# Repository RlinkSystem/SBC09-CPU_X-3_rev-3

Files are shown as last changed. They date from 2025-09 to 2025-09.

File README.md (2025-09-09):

# SBC09-CPU_X-3_rev-3

Simple SBC design around MC6809 Revision 3

This is the second atemp/test to make a full SBC system based on my old
modem X-3 construction, and keep it simpel.

This was done during Summer holiday 2025.
To test my simple & basic setup, and continue to experiment.

My goal is to have an uncomplex build that is not compact, so:
* not with a few large ICs
* not with PAL/GAL
* and with "many" ICs

So my setup is:
* CPU: MC68B09/HD63C09
* MEM: 7x HM6264ALP-15
* ROM: 2764 eq EPROM / EEPROM
* PTM: MC6840
* ACIA: 2x MC6850
* ACIA: R6551
* PIA: 3x MC6821
* Glue logic:
  * 74HCT04
  * 4x 74HCT138
  * 74HCT4040 Baud Rate
* Test support for USB-TTL-UART
  * CH340E (CH340X)

My testing setup:
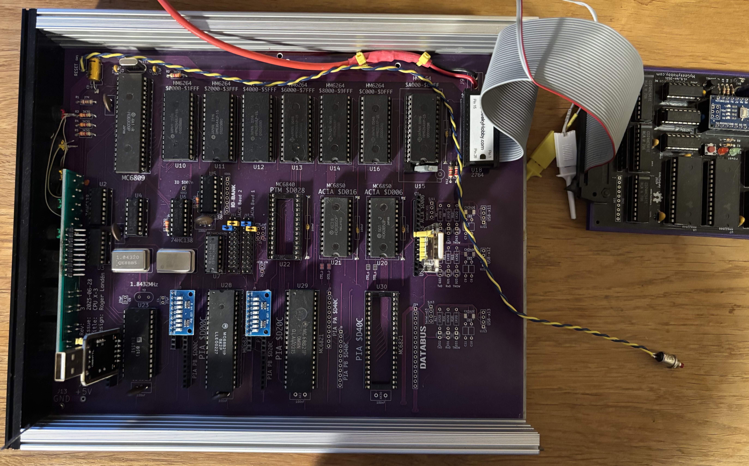
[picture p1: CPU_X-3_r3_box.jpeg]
PCB in case


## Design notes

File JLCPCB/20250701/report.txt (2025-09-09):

Plotted to '/Users/rogerlanden/Z180/6809/CPU_X-3/CPU_X-3-v2/JLCPCB/PCB_CPU_X-3_v2/PCB_CPU_X_3/CPU_X-3-F_Cu.gtl'.
Plotted to '/Users/rogerlanden/Z180/6809/CPU_X-3/CPU_X-3-v2/JLCPCB/PCB_CPU_X-3_v2/PCB_CPU_X_3/CPU_X-3-B_Cu.gbl'.
Plotted to '/Users/rogerlanden/Z180/6809/CPU_X-3/CPU_X-3-v2/JLCPCB/PCB_CPU_X-3_v2/PCB_CPU_X_3/CPU_X-3-F_Paste.gtp'.
Plotted to '/Users/rogerlanden/Z180/6809/CPU_X-3/CPU_X-3-v2/JLCPCB/PCB_CPU_X-3_v2/PCB_CPU_X_3/CPU_X-3-B_Paste.gbp'.
Plotted to '/Users/rogerlanden/Z180/6809/CPU_X-3/CPU_X-3-v2/JLCPCB/PCB_CPU_X-3_v2/PCB_CPU_X_3/CPU_X-3-F_Silkscreen.gto'.
Plotted to '/Users/rogerlanden/Z180/6809/CPU_X-3/CPU_X-3-v2/JLCPCB/PCB_CPU_X-3_v2/PCB_CPU_X_3/CPU_X-3-B_Silkscreen.gbo'.
Plotted to '/Users/rogerlanden/Z180/6809/CPU_X-3/CPU_X-3-v2/JLCPCB/PCB_CPU_X-3_v2/PCB_CPU_X_3/CPU_X-3-F_Mask.gts'.
Plotted to '/Users/rogerlanden/Z180/6809/CPU_X-3/CPU_X-3-v2/JLCPCB/PCB_CPU_X-3_v2/PCB_CPU_X_3/CPU_X-3-B_Mask.gbs'.
Plotted to '/Users/rogerlanden/Z180/6809/CPU_X-3/CPU_X-3-v2/JLCPCB/PCB_CPU_X-3_v2/PCB_CPU_X_3/CPU_X-3-Edge_Cuts.gm1'.
Info: Done.
Info: Done.

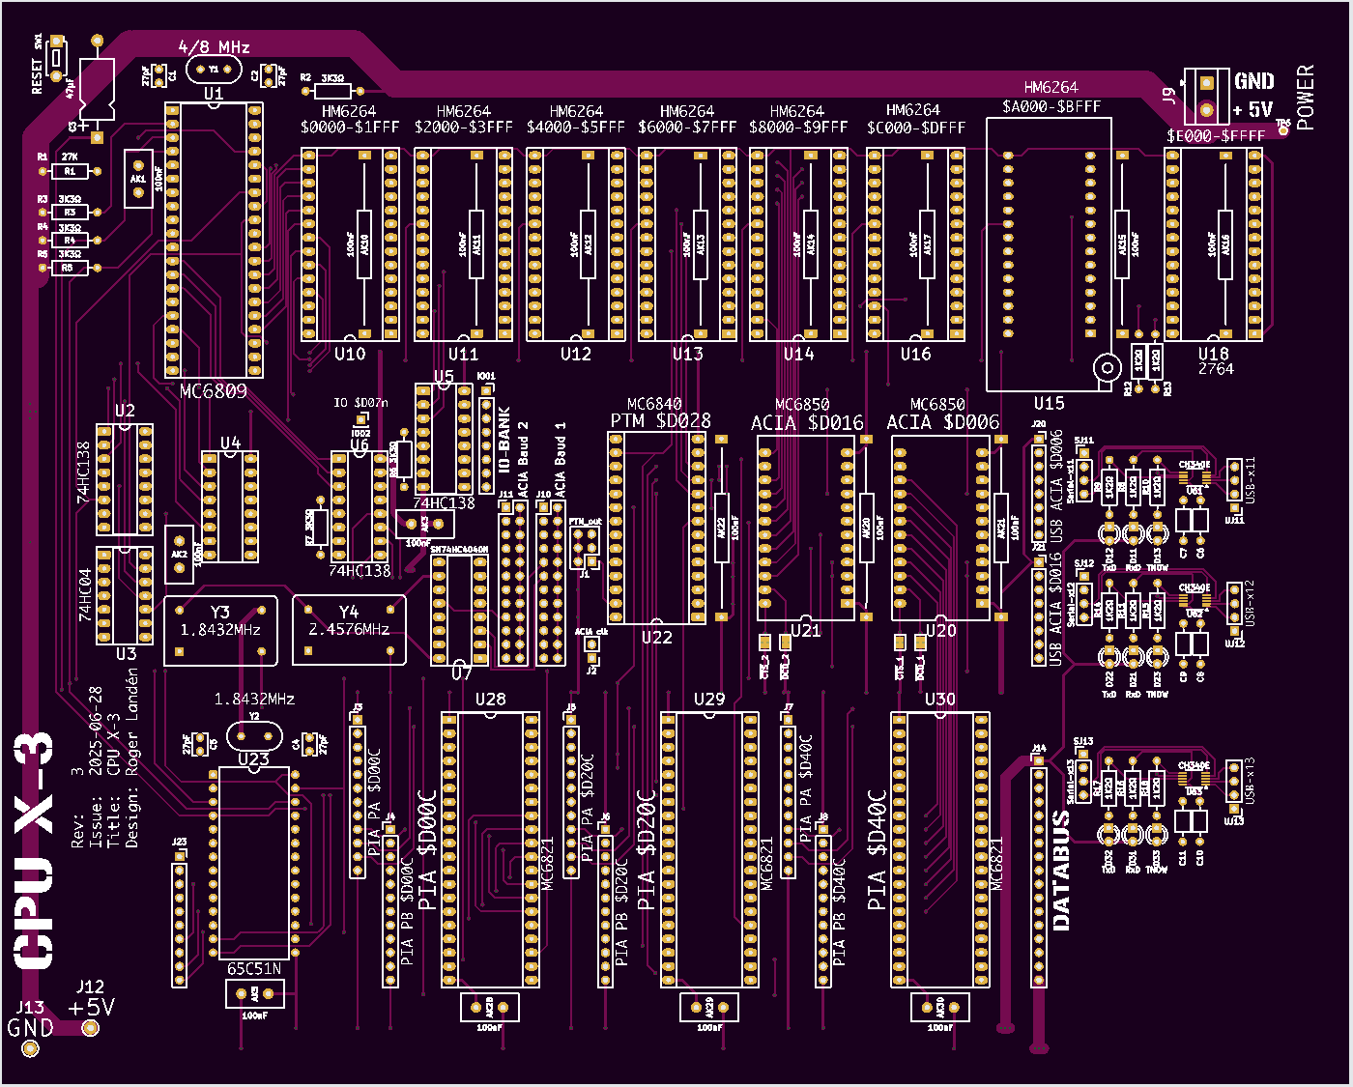
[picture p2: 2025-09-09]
JLCPCB/20250701/PCB_Lila_top.png

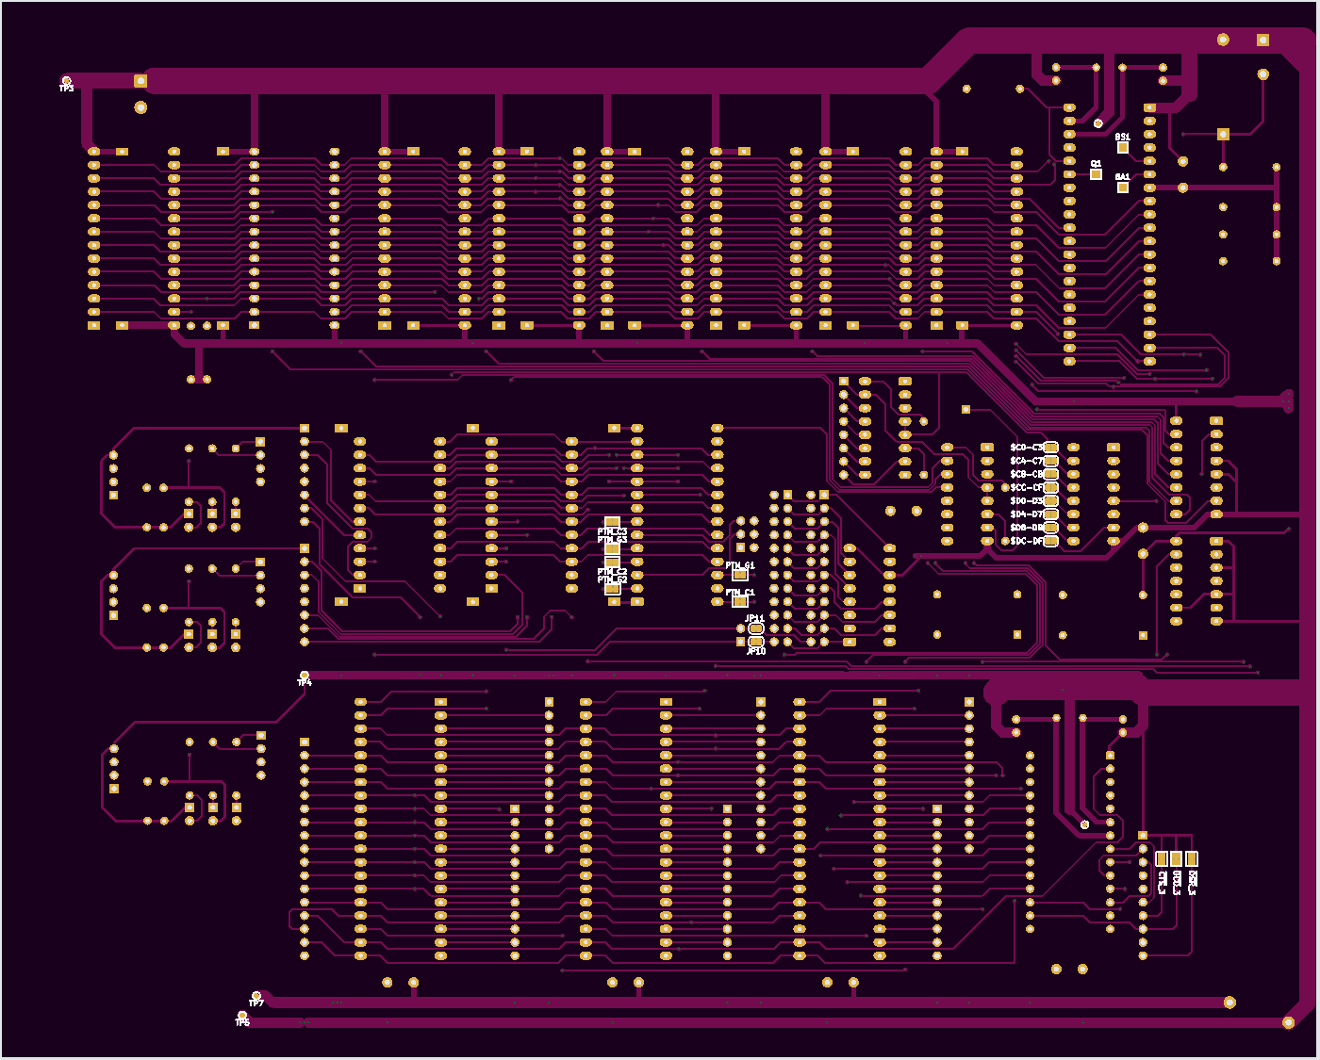
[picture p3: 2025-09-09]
JLCPCB/20250701/PCB_Lila_botom.png

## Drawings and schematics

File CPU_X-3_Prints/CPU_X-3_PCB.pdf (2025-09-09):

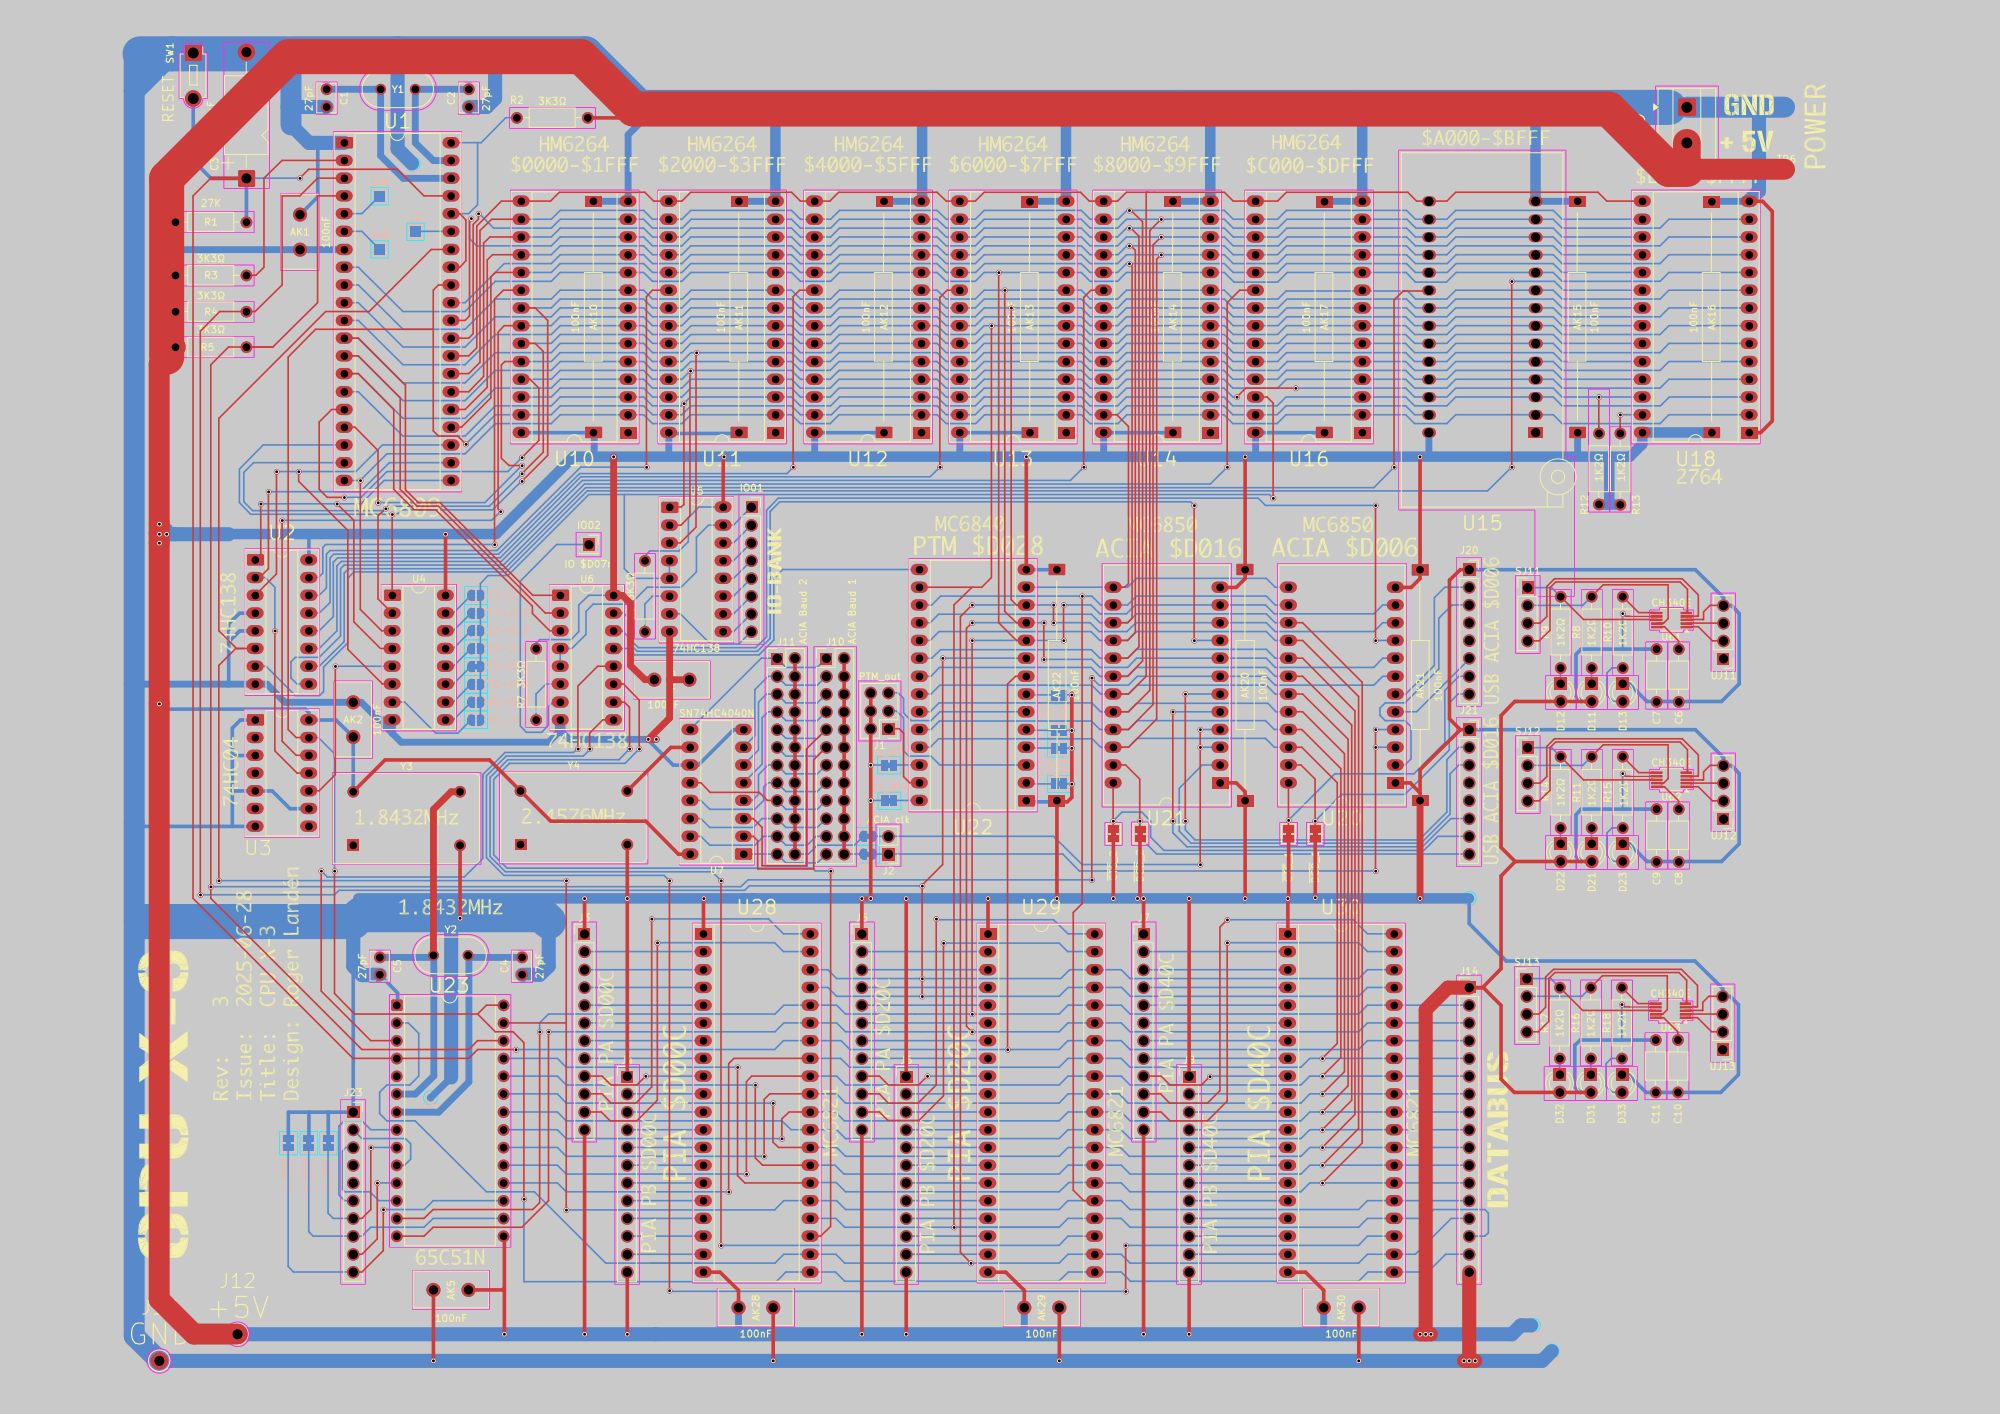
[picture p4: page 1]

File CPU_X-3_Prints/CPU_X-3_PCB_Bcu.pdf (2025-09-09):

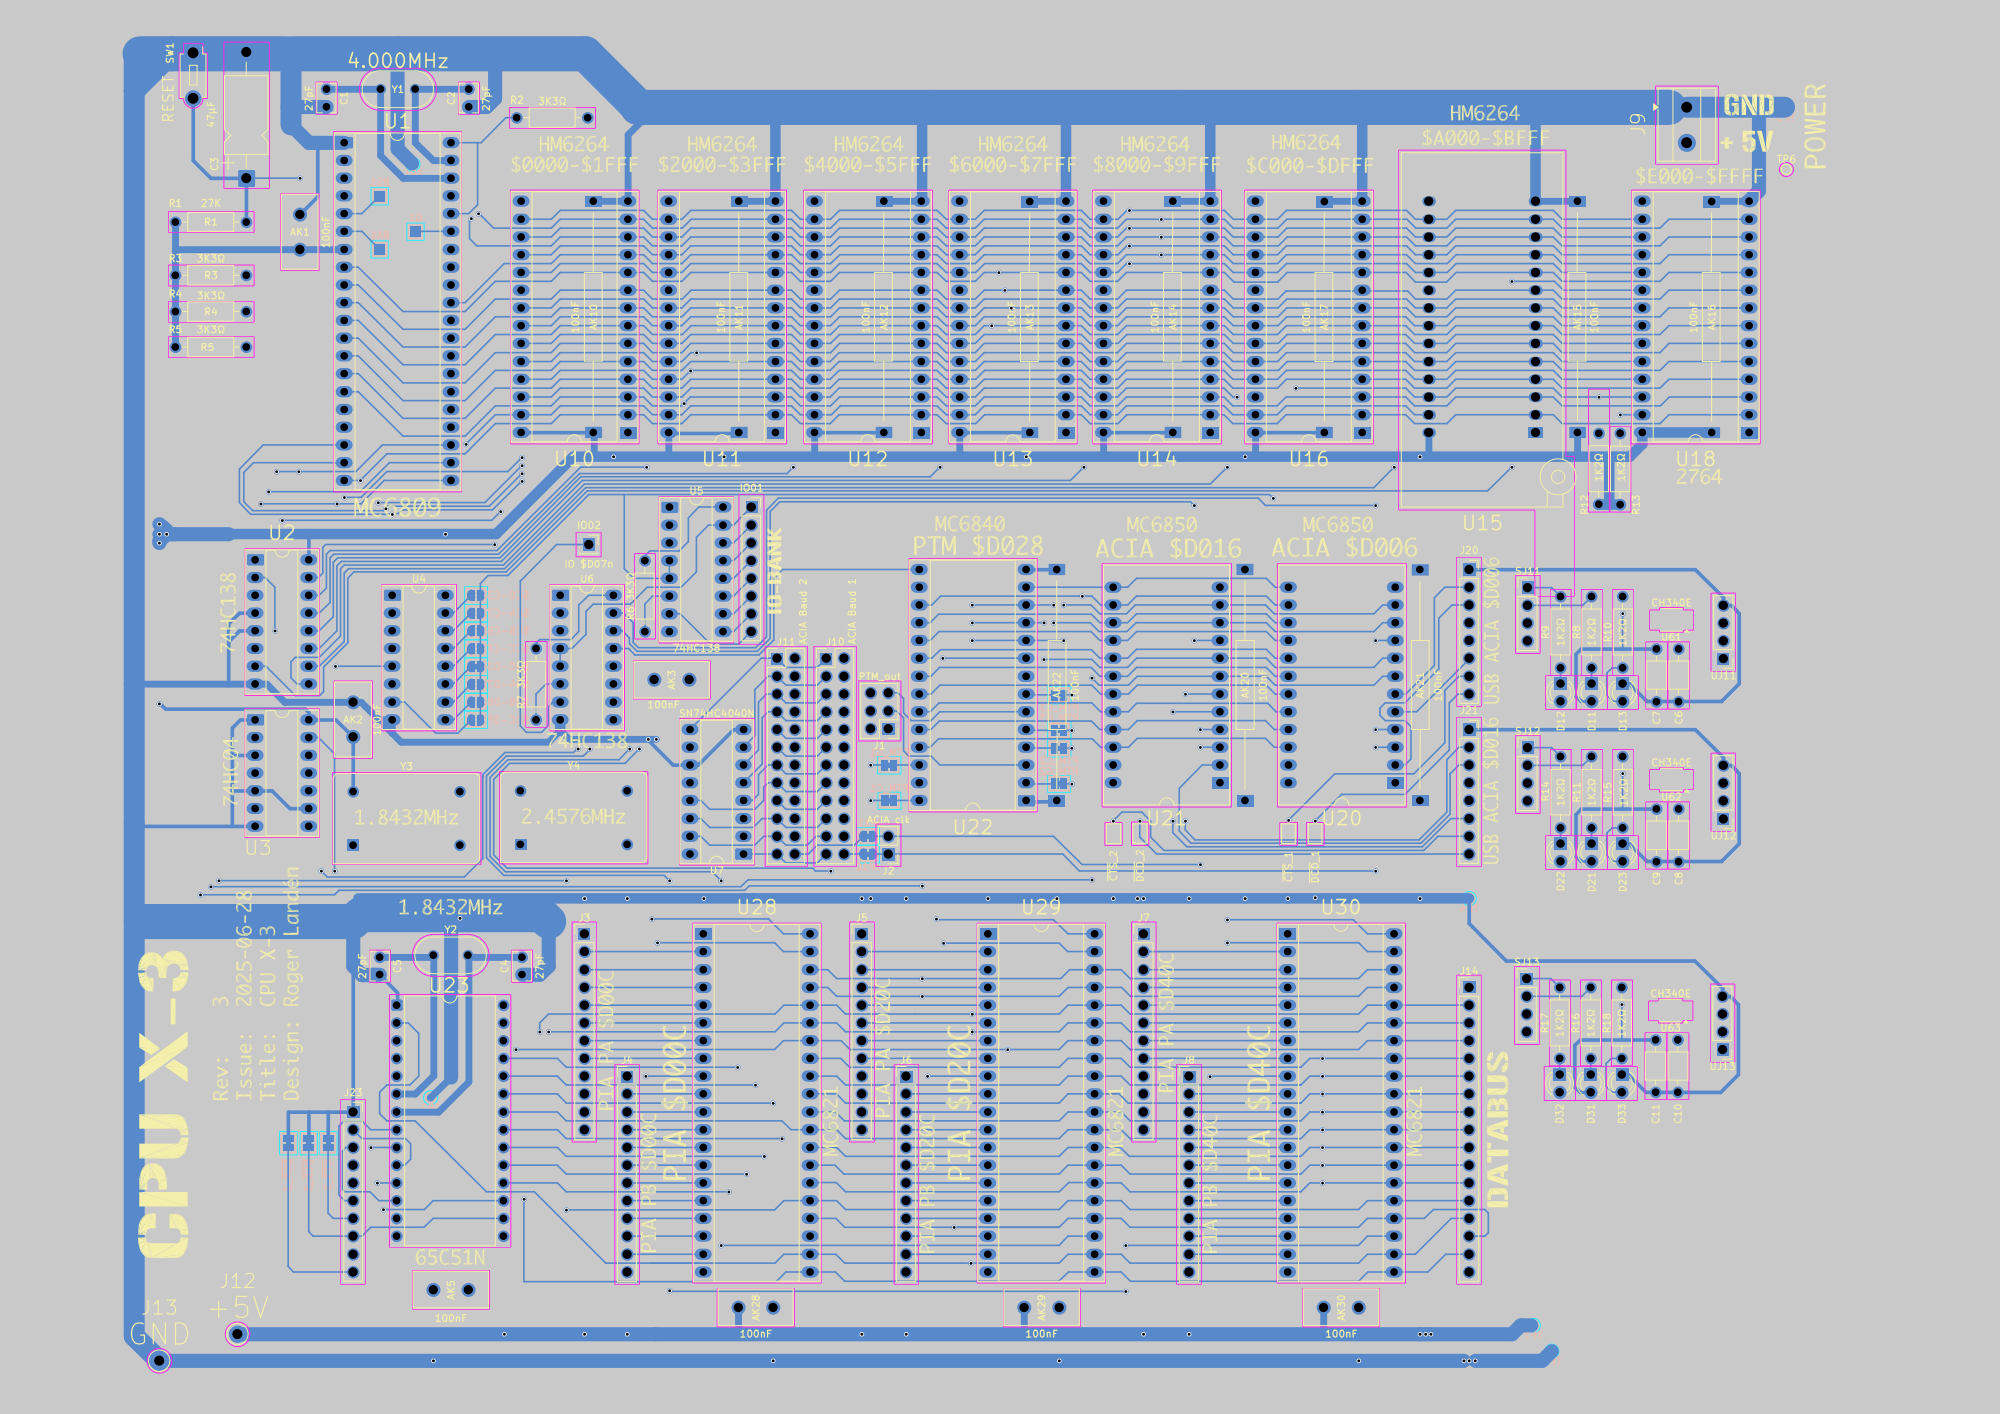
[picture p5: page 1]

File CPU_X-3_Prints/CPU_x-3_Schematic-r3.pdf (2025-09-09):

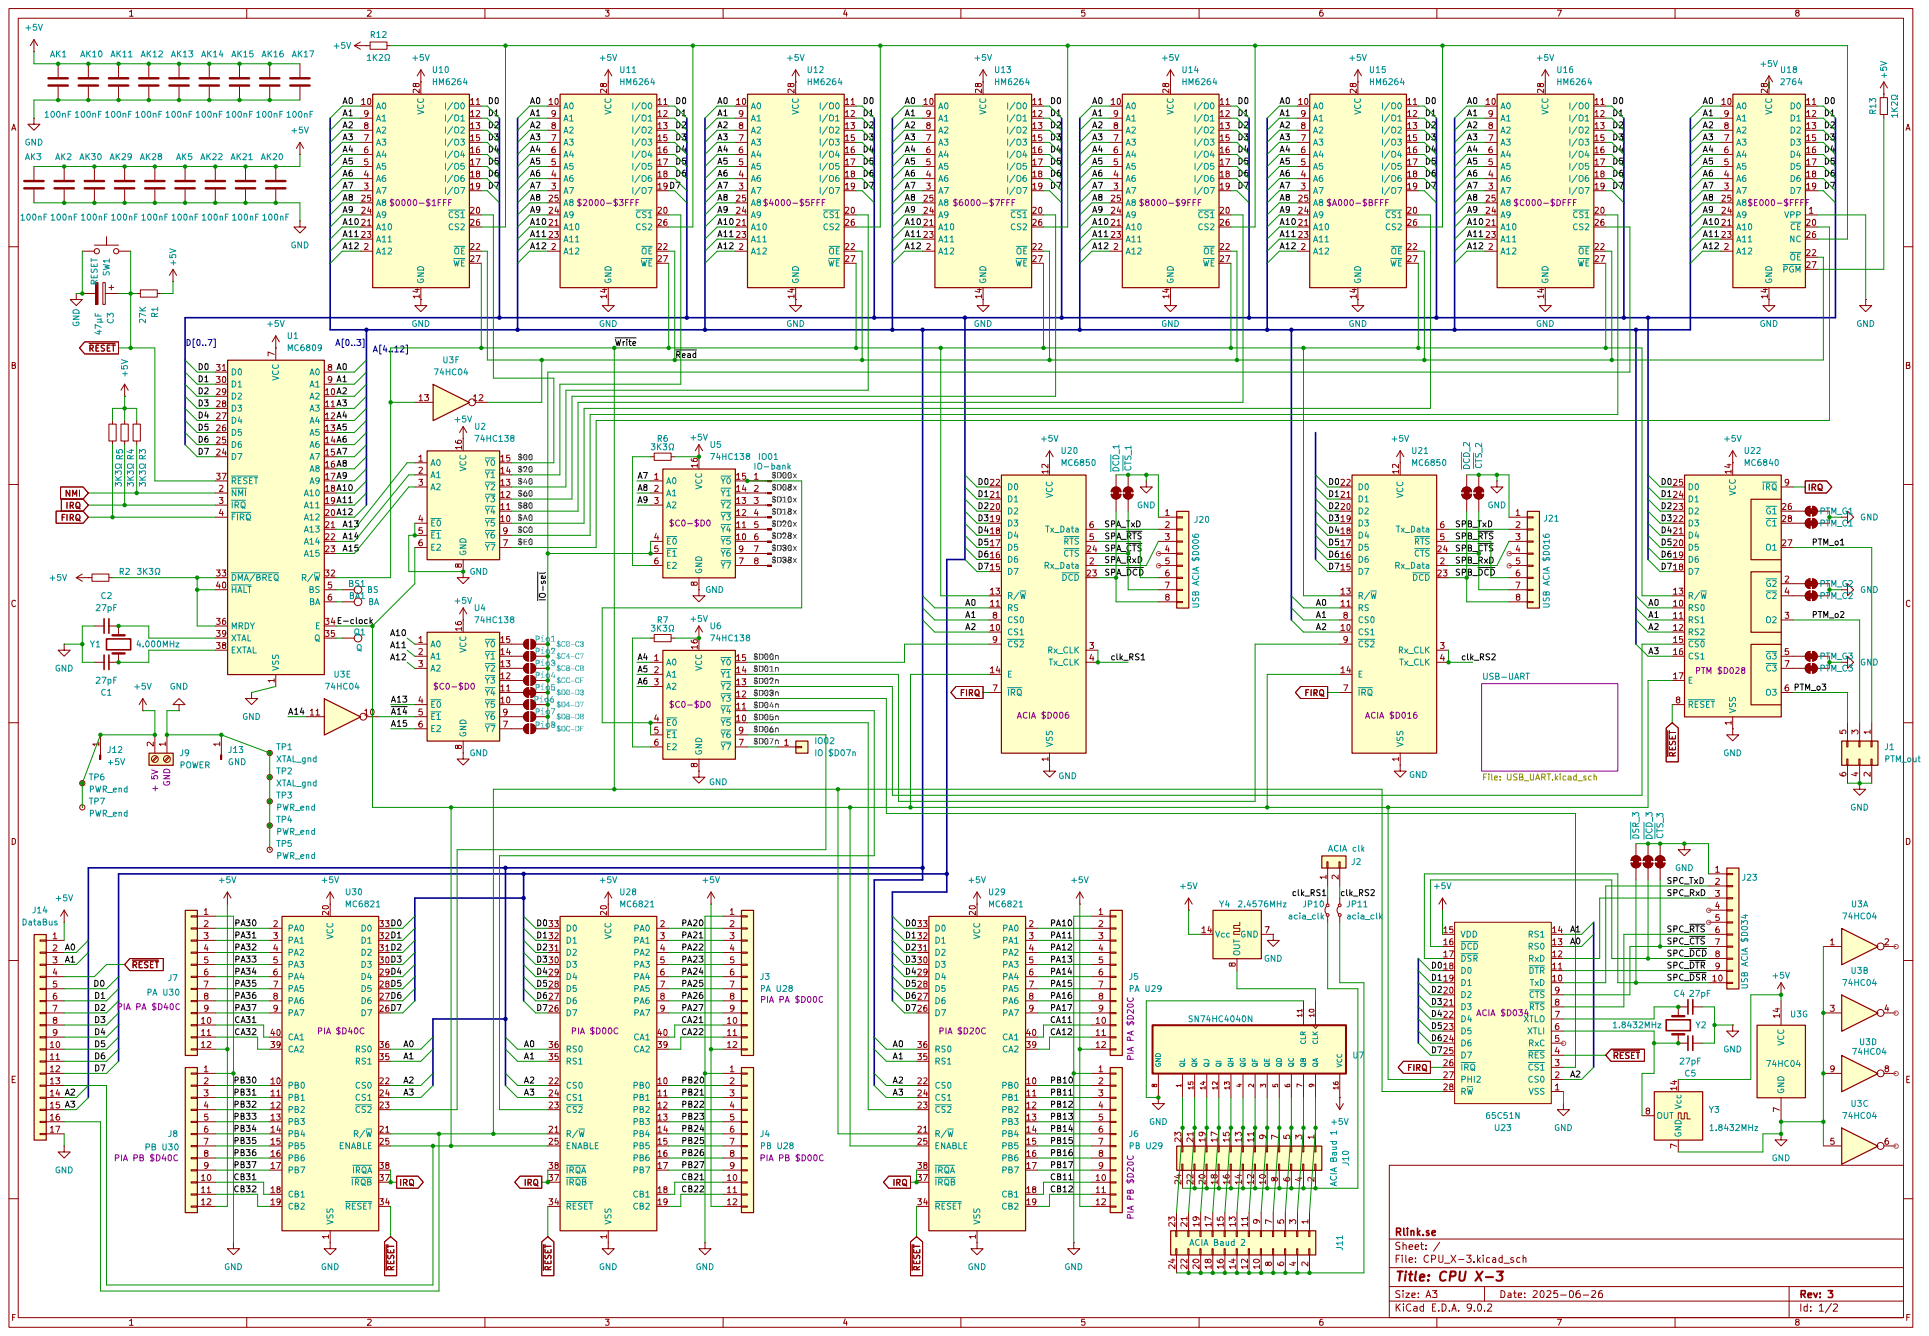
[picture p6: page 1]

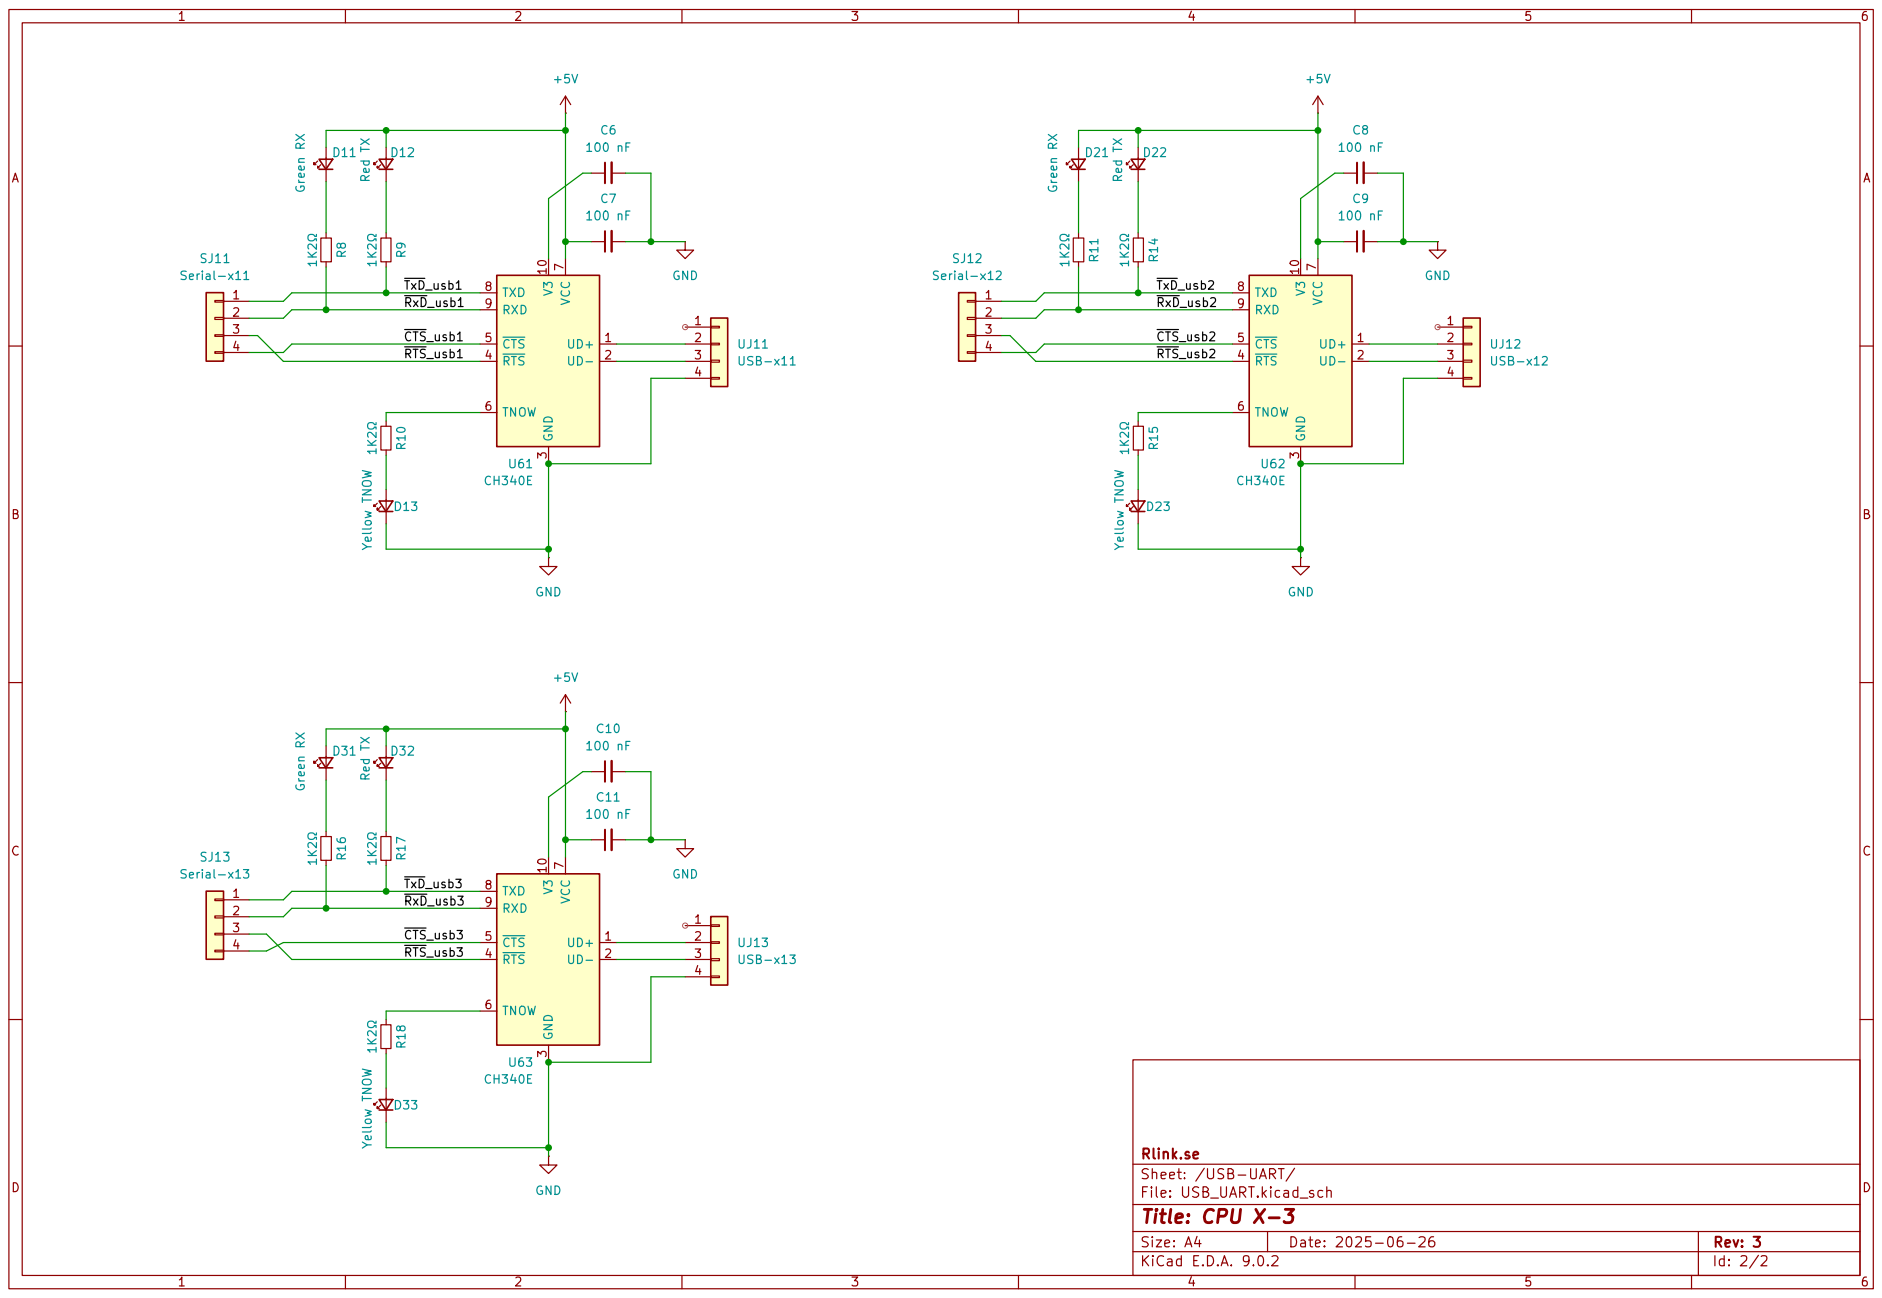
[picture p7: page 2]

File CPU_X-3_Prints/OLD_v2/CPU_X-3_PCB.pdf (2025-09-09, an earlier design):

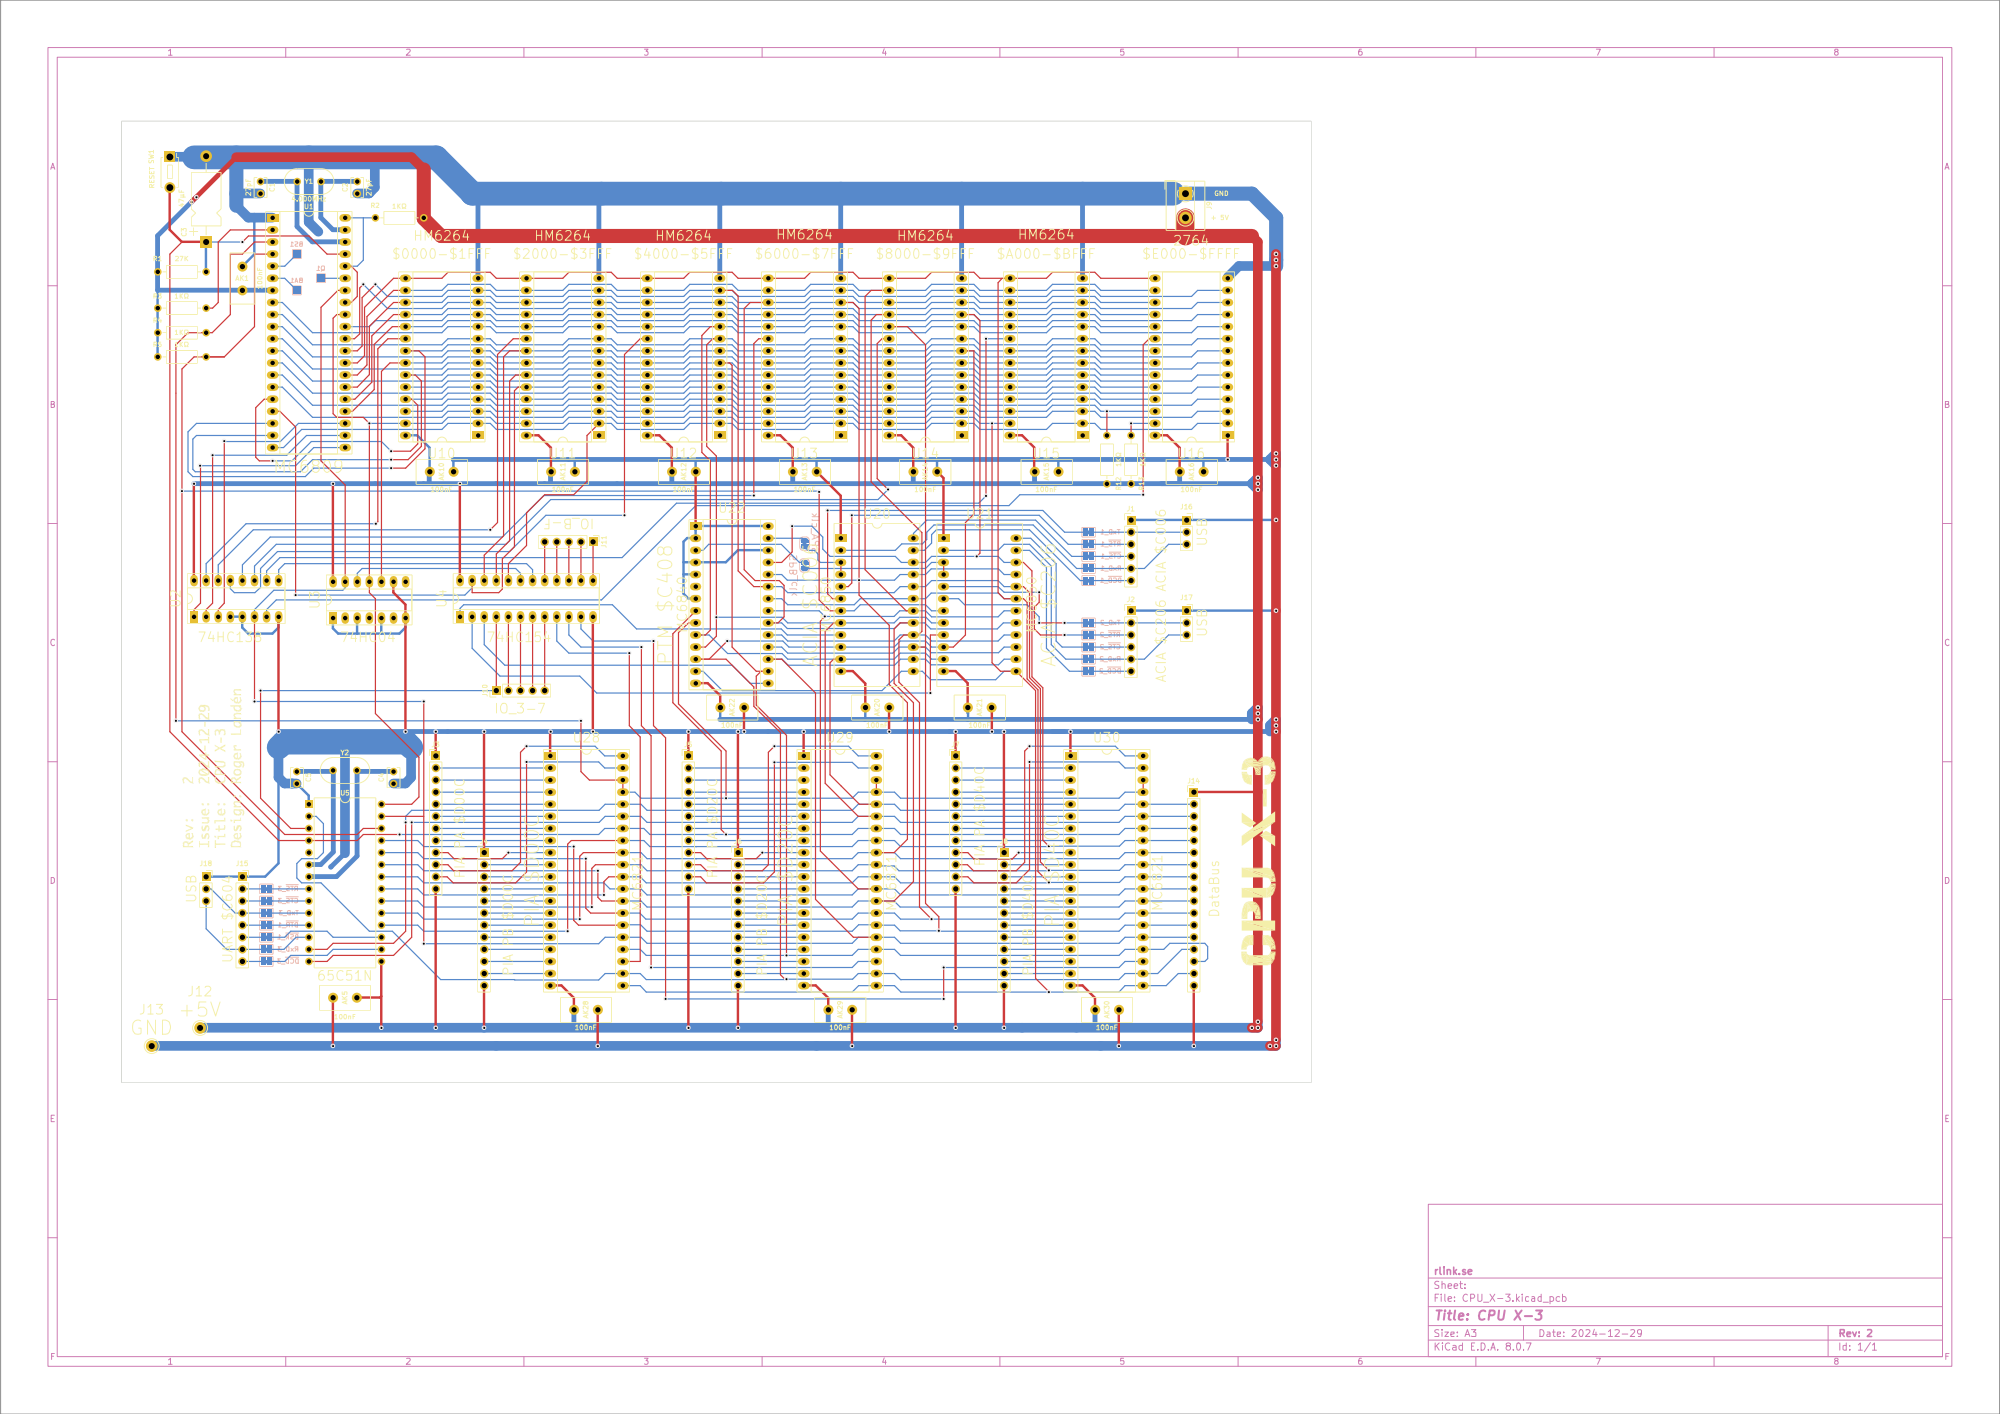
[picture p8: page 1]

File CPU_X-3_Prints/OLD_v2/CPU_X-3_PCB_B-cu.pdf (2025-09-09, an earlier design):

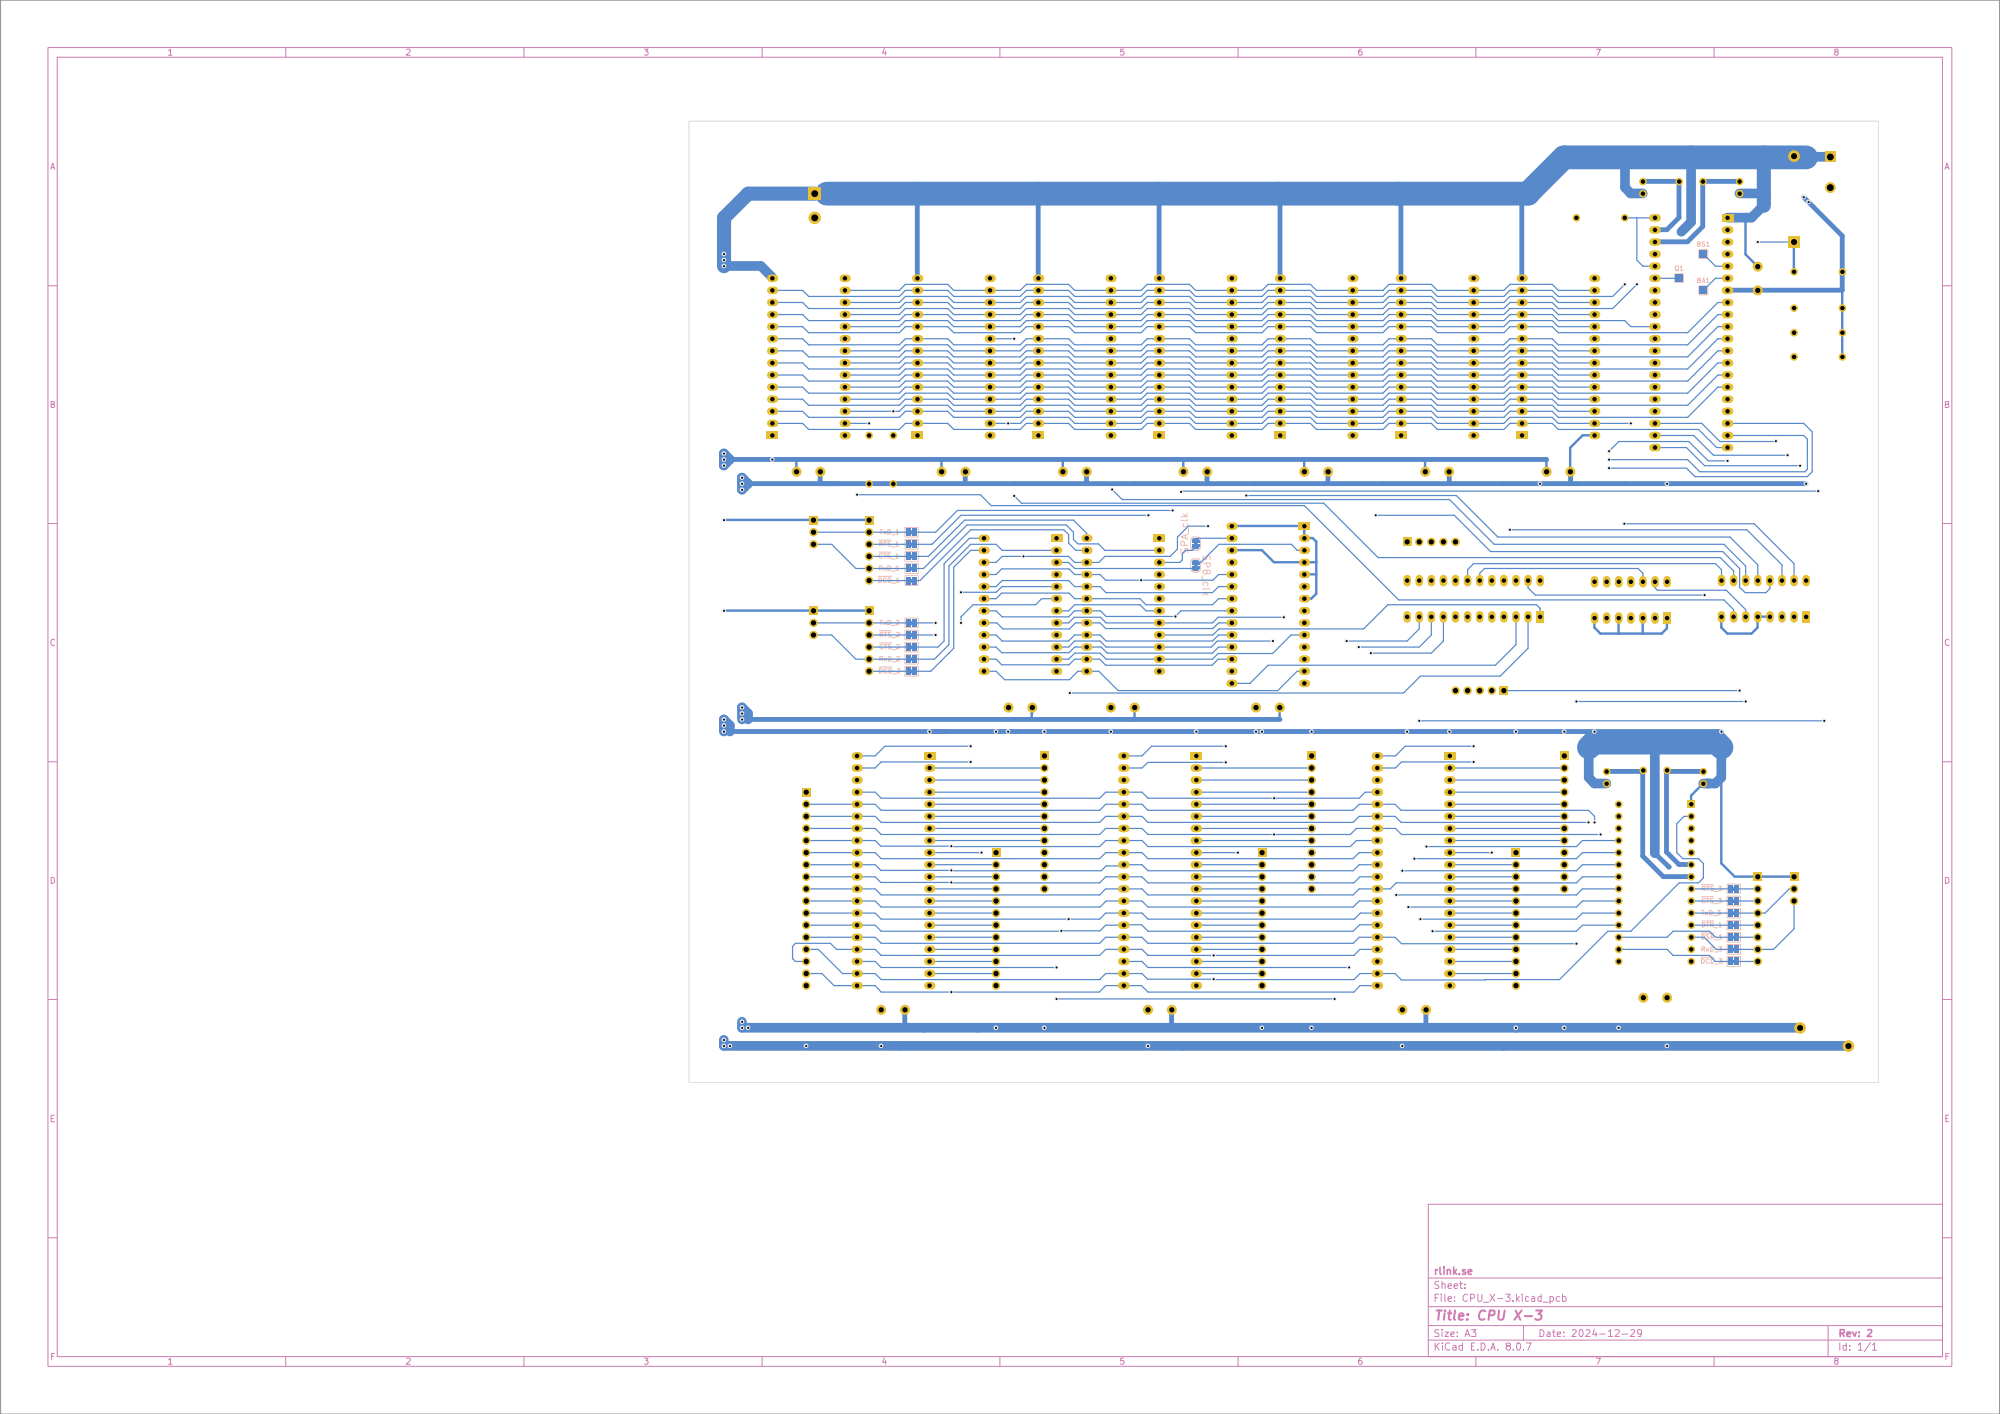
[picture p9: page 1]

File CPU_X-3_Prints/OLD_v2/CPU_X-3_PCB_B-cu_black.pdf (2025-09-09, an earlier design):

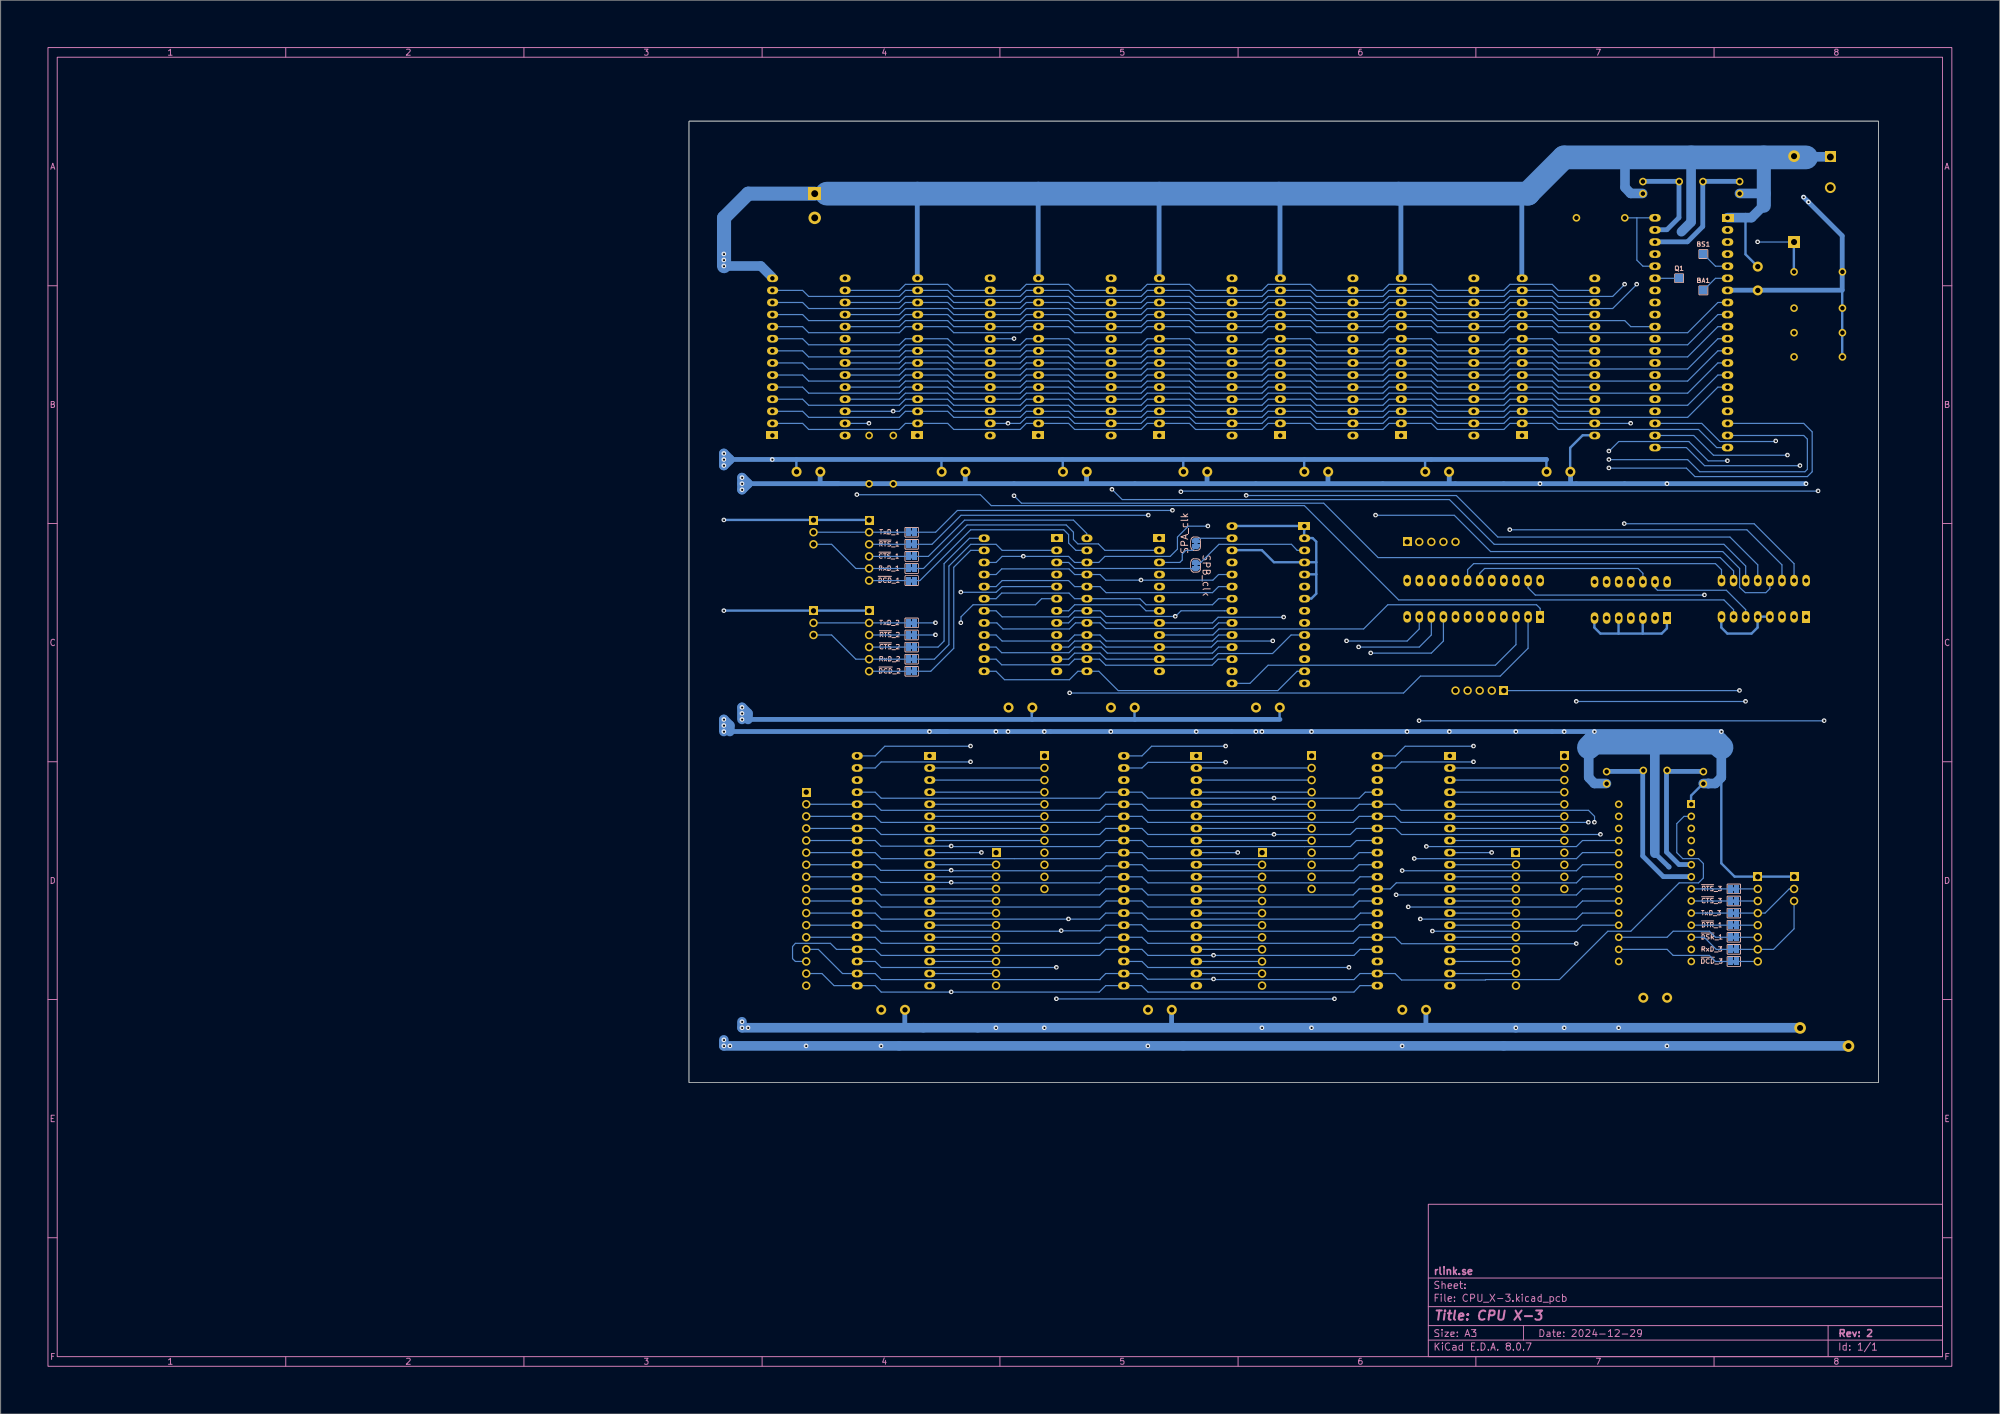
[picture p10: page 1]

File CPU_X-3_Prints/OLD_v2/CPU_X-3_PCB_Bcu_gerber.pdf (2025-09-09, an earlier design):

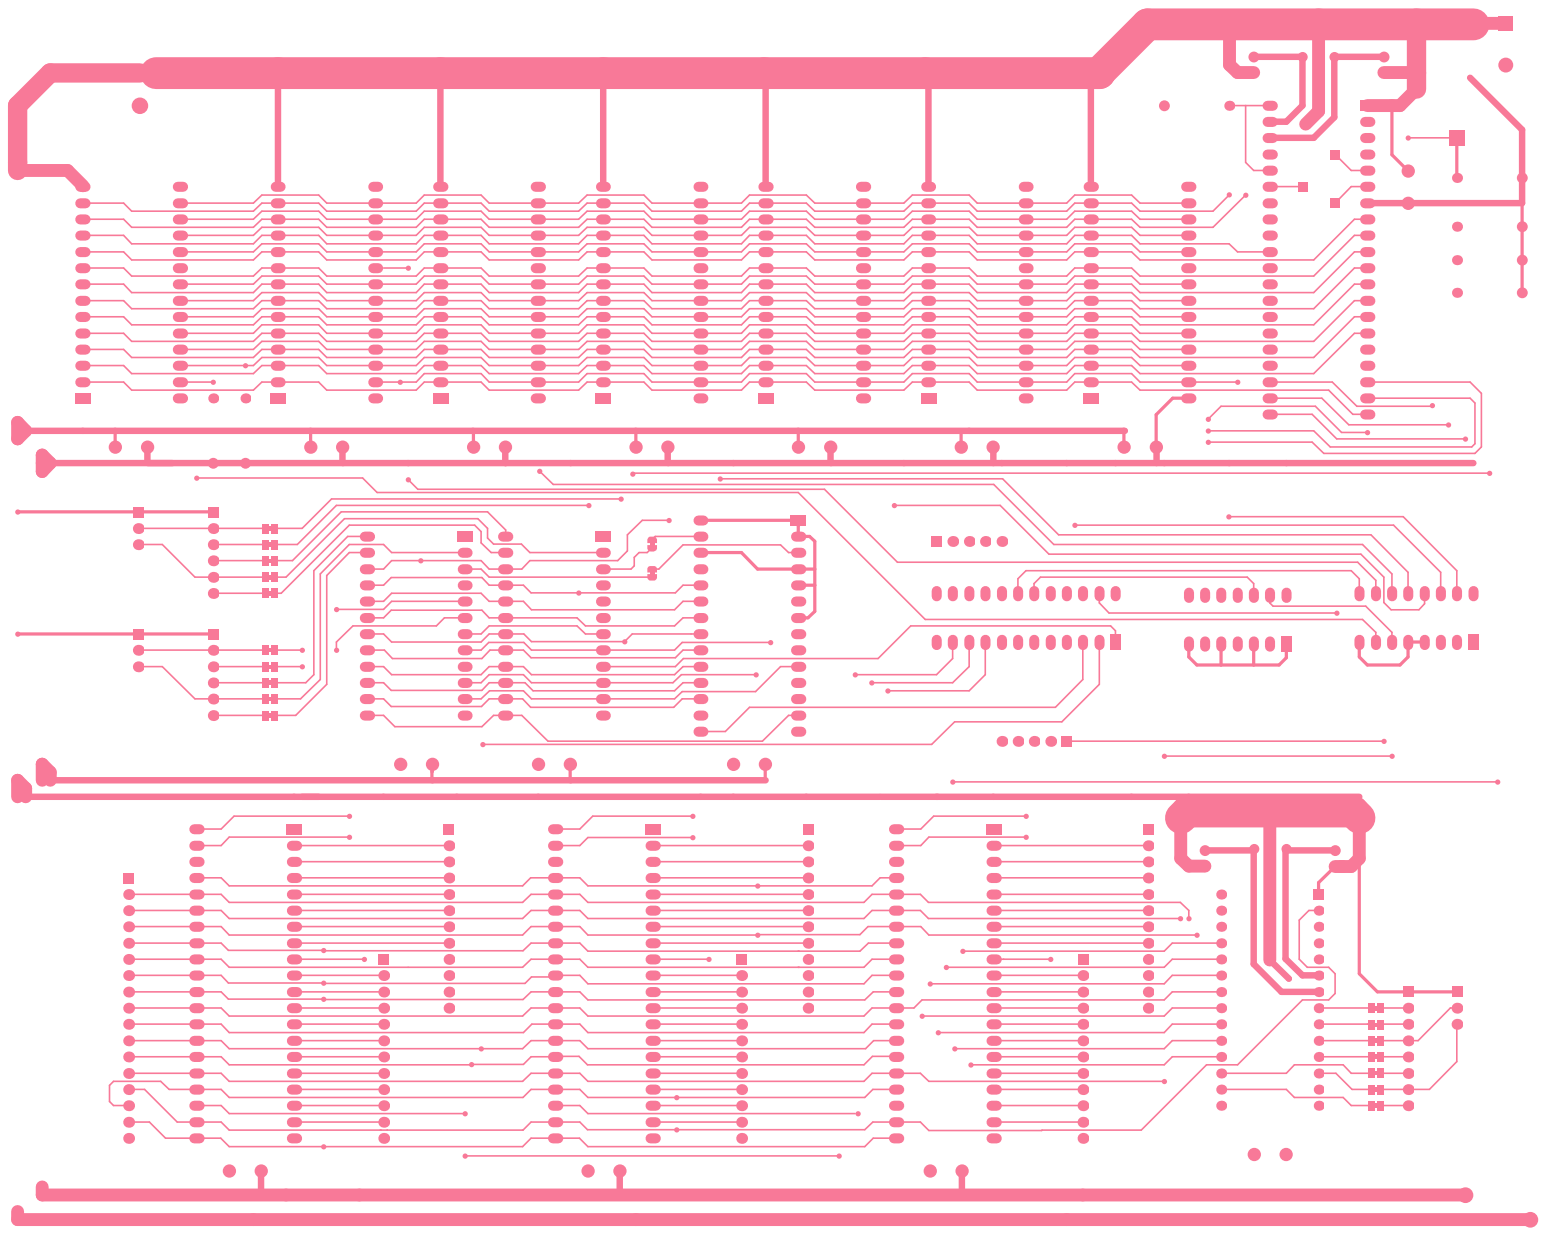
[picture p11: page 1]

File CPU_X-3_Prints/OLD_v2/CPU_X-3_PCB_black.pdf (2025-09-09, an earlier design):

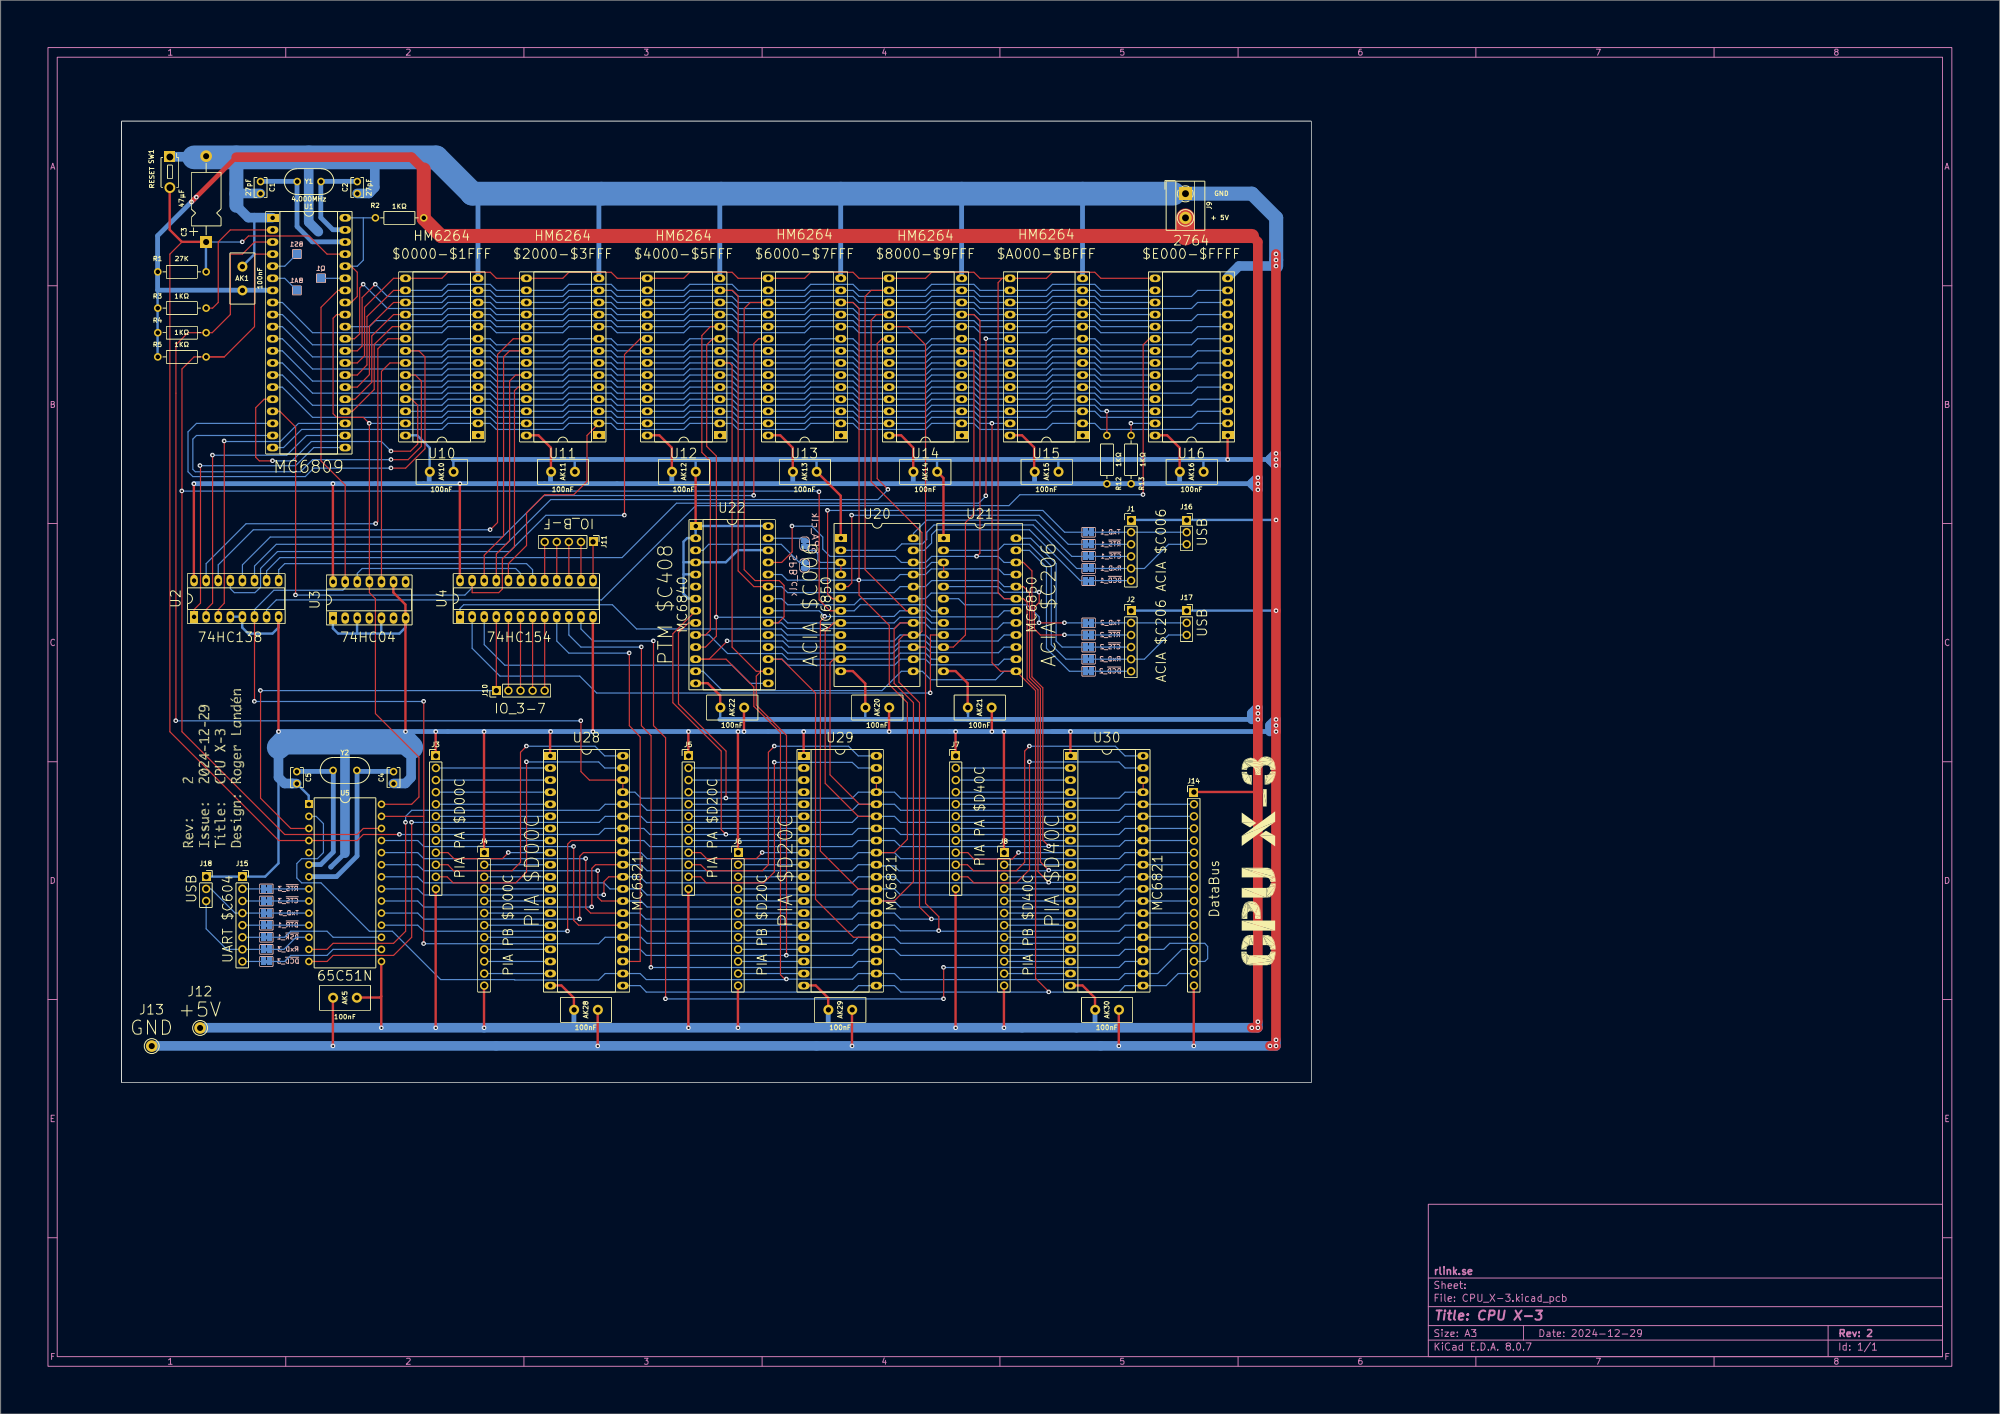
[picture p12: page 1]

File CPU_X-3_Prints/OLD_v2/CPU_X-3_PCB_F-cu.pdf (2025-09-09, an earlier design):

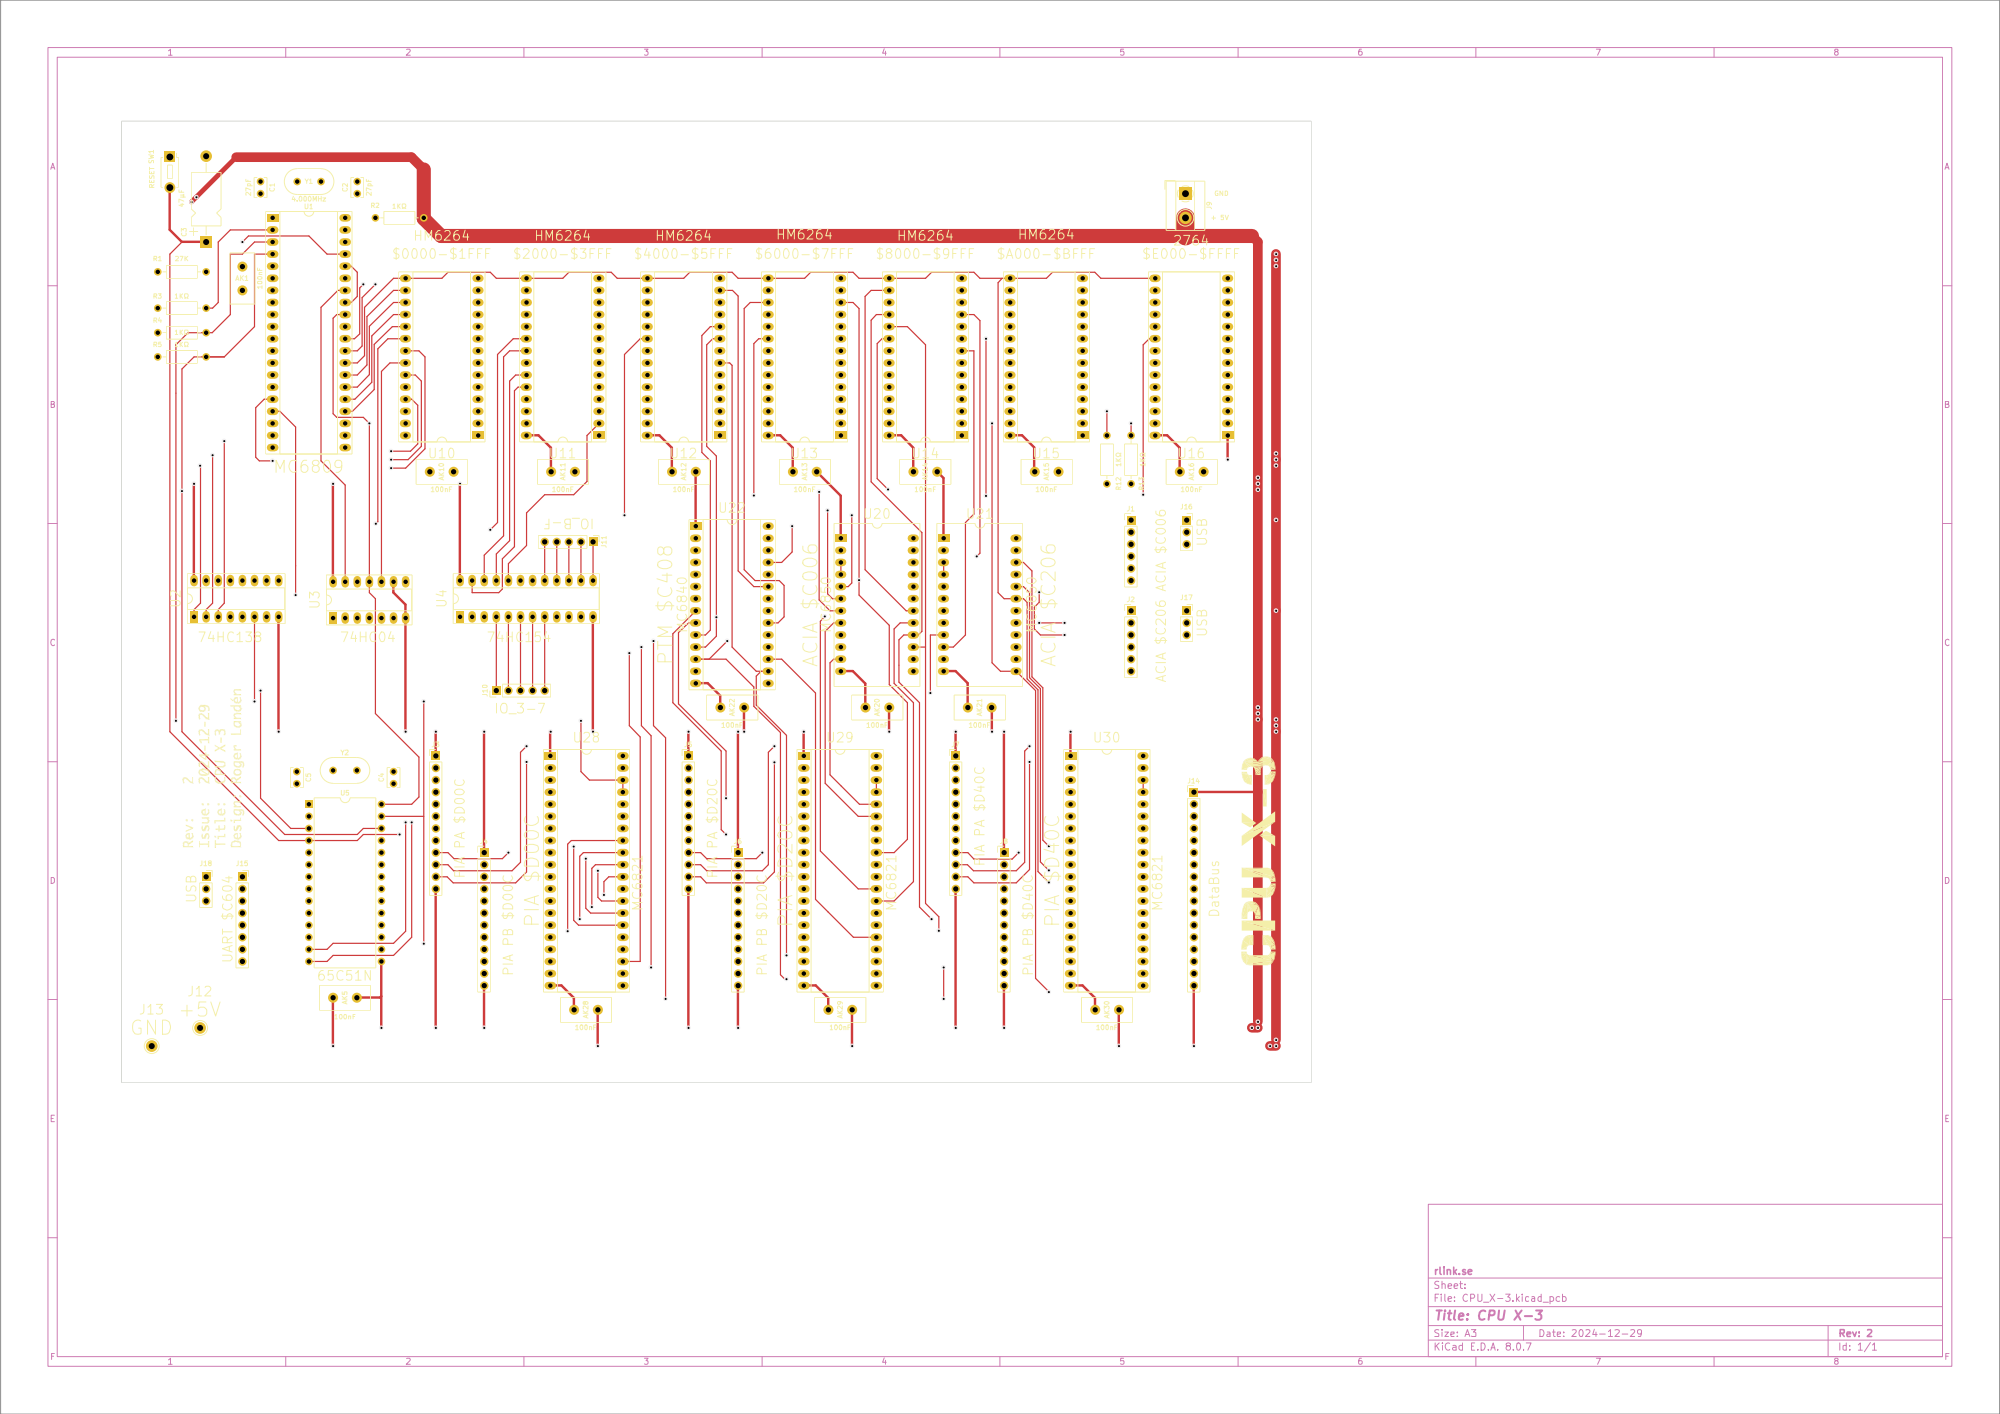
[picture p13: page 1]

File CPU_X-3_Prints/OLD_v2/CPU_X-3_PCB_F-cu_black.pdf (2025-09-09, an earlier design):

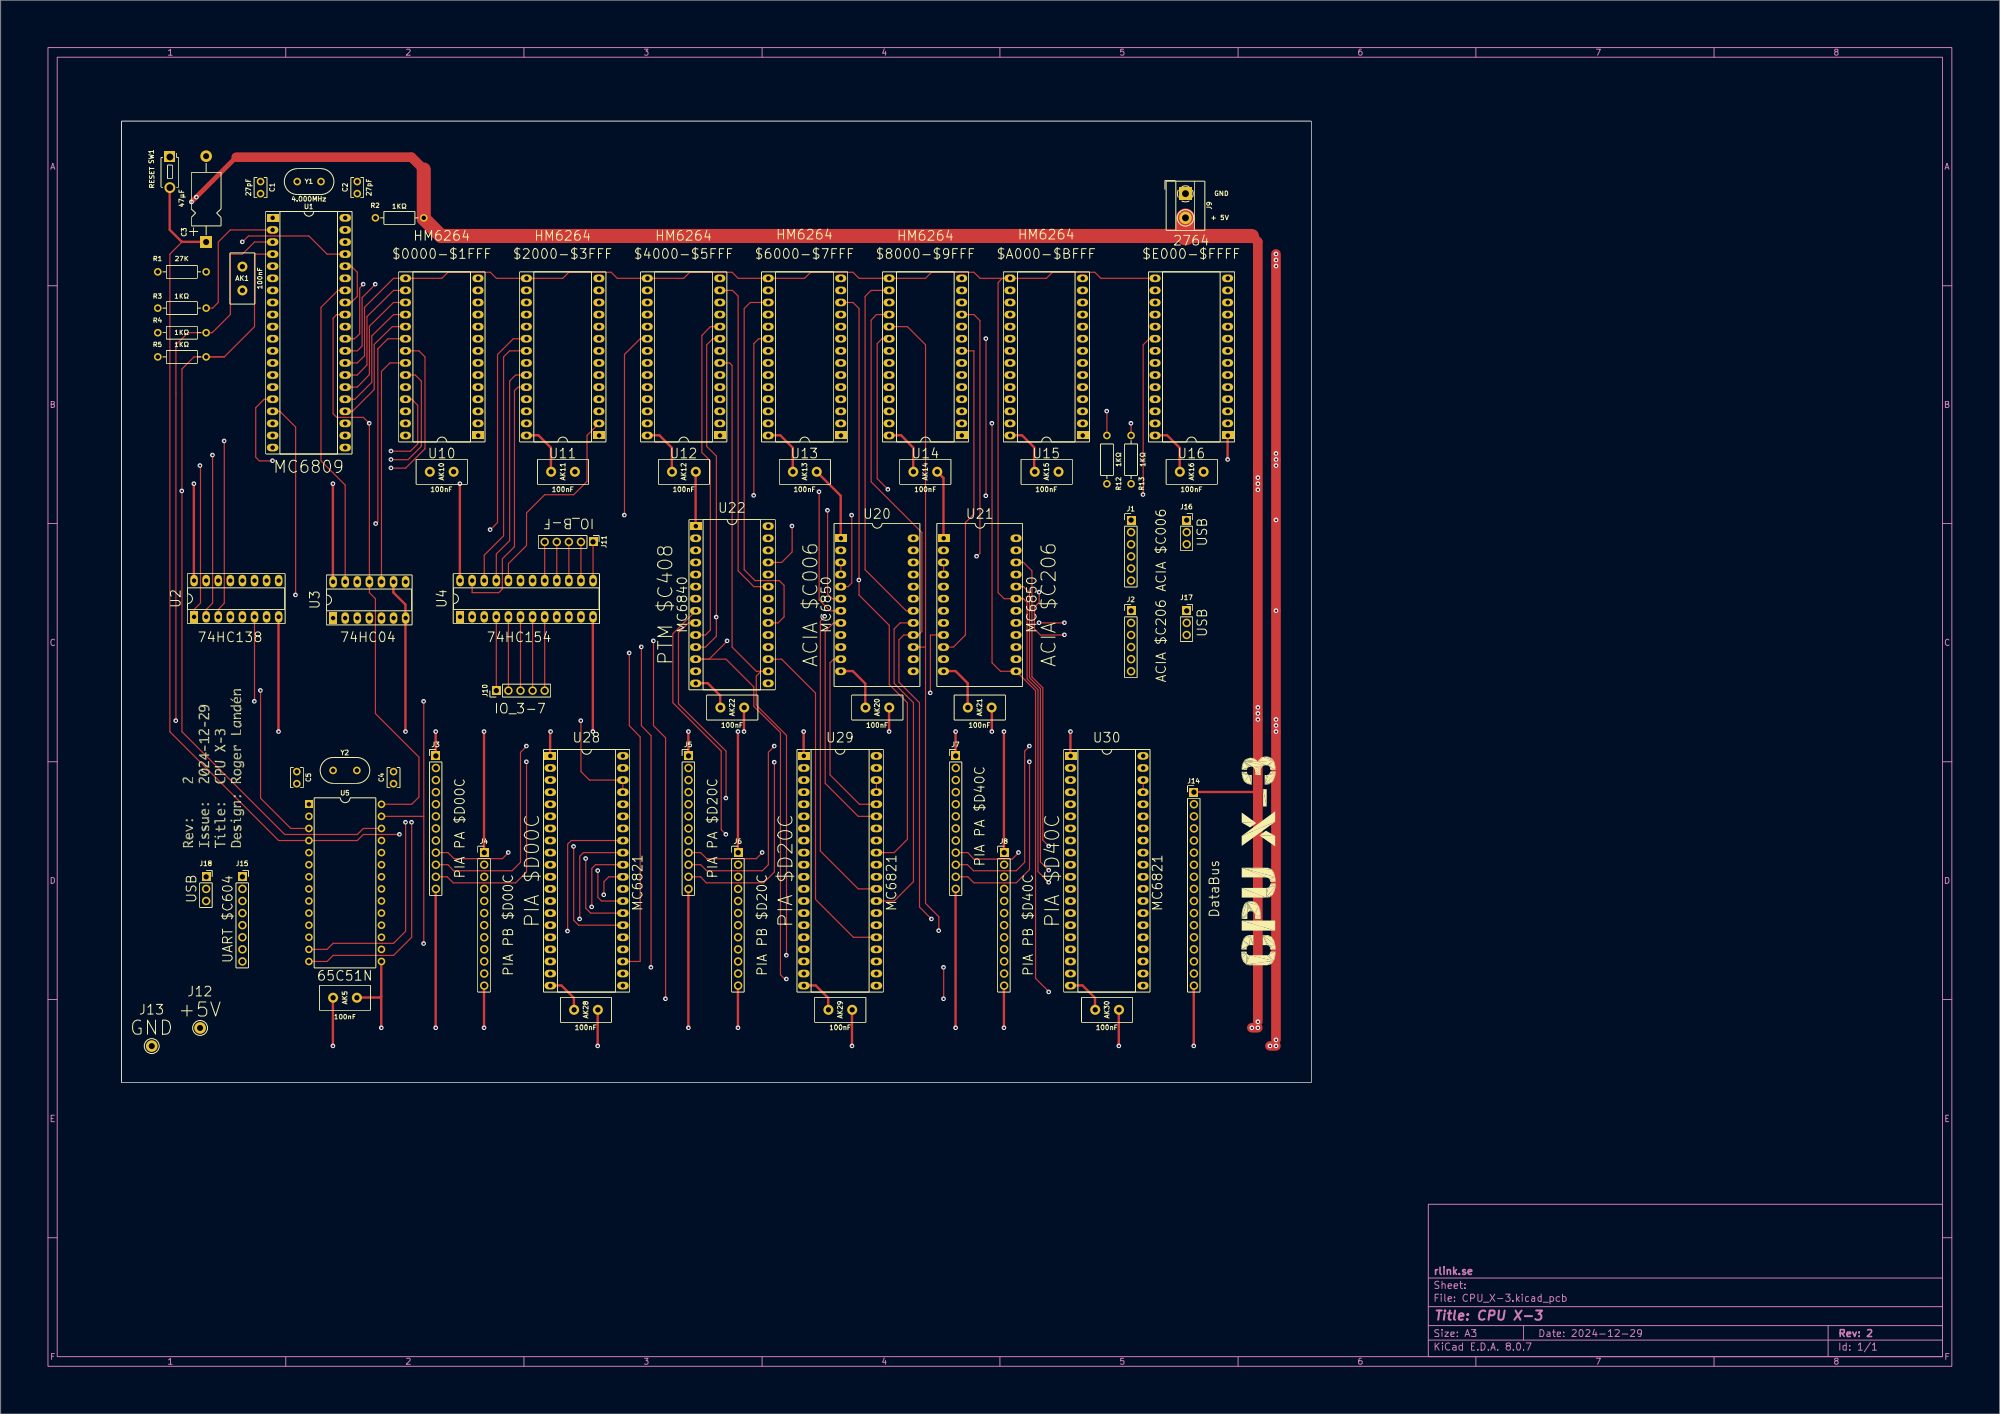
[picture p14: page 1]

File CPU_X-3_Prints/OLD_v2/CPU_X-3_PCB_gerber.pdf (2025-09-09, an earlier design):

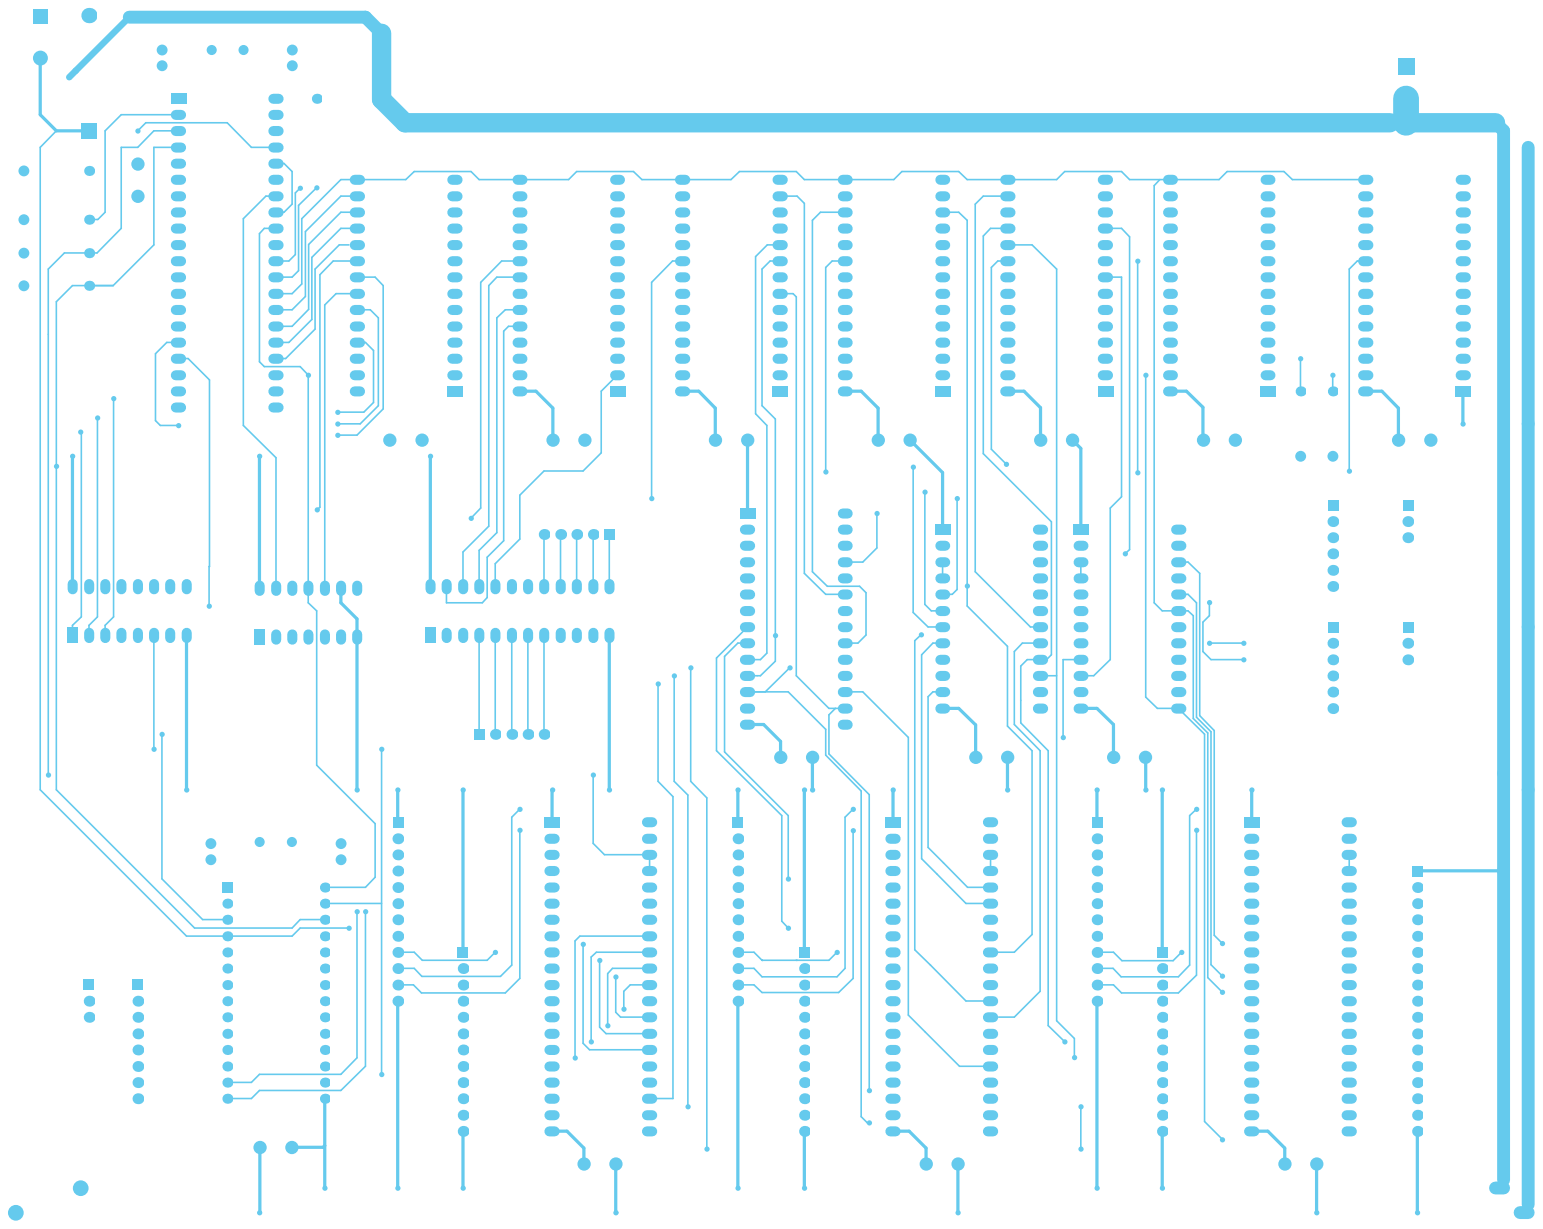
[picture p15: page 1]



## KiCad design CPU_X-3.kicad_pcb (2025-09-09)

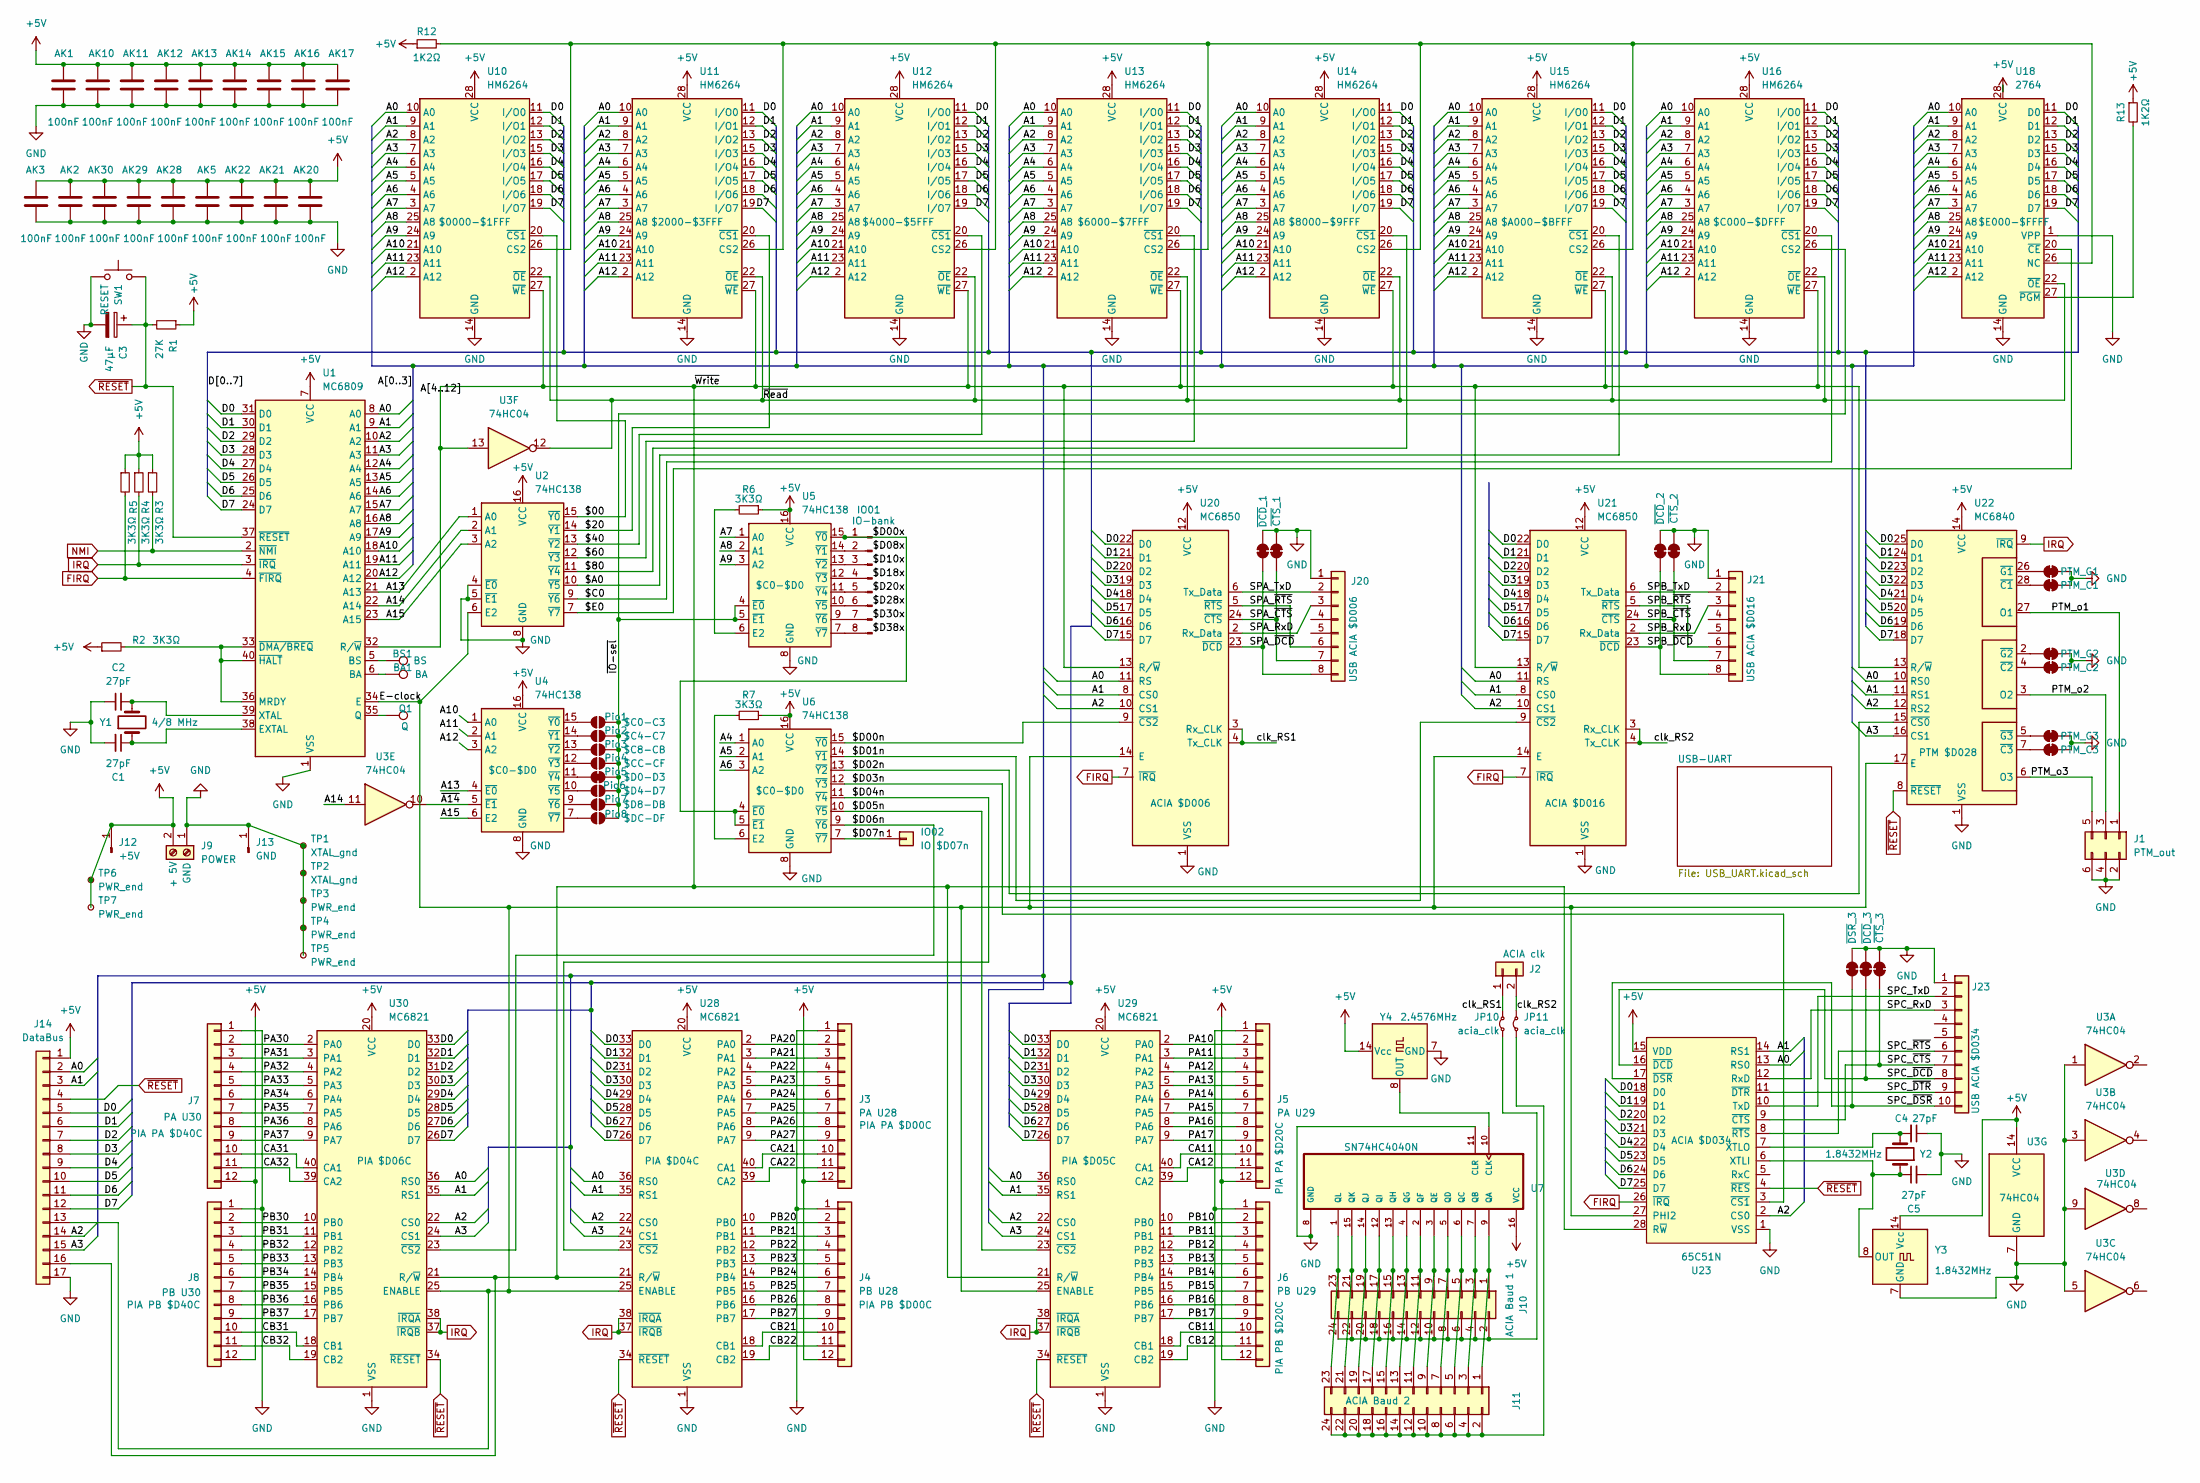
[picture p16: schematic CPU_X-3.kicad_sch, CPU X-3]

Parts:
AK1, AK2, AK3, AK5, AK28, AK29, AK30: 100nF; Avkopplings_C
AK10, AK11, AK12, AK13, AK14, AK15, AK16, AK17, AK20, AK21, AK22: 100nF; Avkoppling_LC
BA1: BA; TestPoint_Pad_1.5x1.5mm
BS1: BS; TestPoint_Pad_1.5x1.5mm
C1, C2, C4, C5: 27pF; C_Rect_L4.0mm_W2.5mm_P2.50mm
C3: 47µF; CP_Axial_L11.0mm_D6.0mm_P18.00mm_Horizontal
IO01: IO-bank; PinSocket_1x08_P2.54mm_Vertical
IO02: IO $D07n; PinSocket_1x01_P2.54mm_Vertical
J1: PTM_out; PinHeader_2x03_P2.54mm_Vertical
J2: ACIA clk; PinHeader_1x02_P2.54mm_Vertical
J3: PA U28; PinHeader_1x12_P2.54mm_Vertical
J4: PB U28; PinHeader_1x12_P2.54mm_Vertical
J5: PA U29; PinHeader_1x12_P2.54mm_Vertical
J6: PB U29; PinHeader_1x12_P2.54mm_Vertical
J7: PA U30; PinHeader_1x12_P2.54mm_Vertical
J8: PB U30; PinHeader_1x12_P2.54mm_Vertical
J9: POWER; TerminalBlock_MetzConnect_Type101_RT01602HBWC_1x02_P5.08mm_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
J10: ACIA Baud 1; PinHeader_2x12_P2.54mm_Vertical
J11: ACIA Baud 2; PinHeader_2x12_P2.54mm_Vertical
J12: +5V; Pin_D1.0mm_L10.0mm_LooseFit
J13: GND; Pin_D1.0mm_L10.0mm_LooseFit
J14: DataBus; PinHeader_1x17_P2.54mm_Vertical
J20: USB ACIA $D006; PinSocket_1x08_P2.54mm_Vertical
J21: USB ACIA $D016; PinSocket_1x08_P2.54mm_Vertical
J23: USB ACIA $D034; PinSocket_1x10_P2.54mm_Vertical
JP10, JP11: acia_clk; SolderJumper-2_P1.3mm_Bridged_RoundedPad1.0x1.5mm
PTM_C1, PTM_C2, PTM_C3: PTM_1; SolderJumper-2_P1.3mm_Bridged_Pad1.0x1.5mm
PTM_G1, PTM_G2, PTM_G3: PTM_1; SolderJumper-2_P1.3mm_Bridged_Pad1.0x1.5mm
Pio1: $C0-C3; SolderJumper-2_P1.3mm_Open_RoundedPad1.0x1.5mm
Pio2: $C4-C7; SolderJumper-2_P1.3mm_Open_RoundedPad1.0x1.5mm
Pio3: $C8-CB; SolderJumper-2_P1.3mm_Open_RoundedPad1.0x1.5mm
Pio4: $CC-CF; SolderJumper-2_P1.3mm_Open_RoundedPad1.0x1.5mm
Pio5: $D0-D3; SolderJumper-2_P1.3mm_Bridged_RoundedPad1.0x1.5mm
Pio6: $D4-D7; SolderJumper-2_P1.3mm_Open_RoundedPad1.0x1.5mm
Pio7: $D8-DB; SolderJumper-2_P1.3mm_Open_RoundedPad1.0x1.5mm
Pio8: $DC-DF; SolderJumper-2_P1.3mm_Open_RoundedPad1.0x1.5mm
Q1: Q; TestPoint_Pad_1.5x1.5mm
R1: 27K; R_Axial_DIN0207_L6.3mm_D2.5mm_P10.16mm_Horizontal
R2, R3, R4, R5, R6, R7: 3K3Ω; R_Axial_DIN0207_L6.3mm_D2.5mm_P10.16mm_Horizontal
R12: 1K2Ω; R_Axial_PullUp_long
R13: 1K2Ω; R_Axial_DIN0207_L6.3mm_D2.5mm_P10.16mm_Horizontal
SW1: RESET; SW_PUSH_1P1T_6x3.5mm_H5.0_APEM_MJTP1250
TP1, TP2: XTAL_gnd; TestPoint_Pad_D1.0mm
TP3, TP4, TP5, TP6, TP7: PWR_end; TestPoint_Pad_D1.0mm
U1: MC6809; DIP-40_W15.24mm_Socket_LongPads
U2, U4, U5, U6: 74HC138; DIP-16_W7.62mm_Socket_LongPads
U3: 74HC04; DIP-14_W7.62mm_Socket_LongPads
U7: SN74HC4040N; DIP-16_W7.62mm_Socket_LongPads
U10, U11, U12, U13, U14, U16: HM6264; X3-MEM_DIP-28
U15: HM6264; DIP_Socket-28_W11.9_W12.7_W15.24_W17.78_W18.5_3M_228-1277-0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
U18: 2764; X3-MEM_DIP-28
U20, U21: MC6850; DIP-24_18.0mmx34.29mm_W15.24mm_Socket_LongPads
U22: MC6840; DIP-28_W15.24mm_Socket_LongPads
U23: 65C51N; DIP-28_W15.24mm
U28, U29, U30: MC6821; X3-IO_DIP-40
Y1: 4/8 MHz; Resonator-2Pin_W10.0mm_H5.0mm
Y2: 1.8432MHz; Resonator-2Pin_W10.0mm_H5.0mm
Y3: 1.8432MHz; Oscillator_DIP-14
Y4: 2.4576MHz; Oscillator_DIP-14
~{CTS}_1: UART-A; SolderJumper-2_P1.3mm_Bridged_Pad1.0x1.5mm
~{CTS}_2: UART-B; SolderJumper-2_P1.3mm_Bridged_Pad1.0x1.5mm
~{CTS}_3: UART-C; SolderJumper-2_P1.3mm_Bridged_Pad1.0x1.5mm
~{DCD}_1: UART-A; SolderJumper-2_P1.3mm_Bridged_Pad1.0x1.5mm
~{DCD}_2: UART-B; SolderJumper-2_P1.3mm_Bridged_Pad1.0x1.5mm
~{DCD}_3: UART-C; SolderJumper-2_P1.3mm_Bridged_Pad1.0x1.5mm
~{DSR}_3: UART-C; SolderJumper-2_P1.3mm_Bridged_Pad1.0x1.5mm

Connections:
+5V: AK1.1, AK2.1, AK3.1, AK5.1, AK10.1, AK11.1, AK12.1, AK13.1, AK14.1, AK15.1, AK16.1, AK17.1, AK20.1, AK21.1, AK22.1, AK28.1, AK29.1, AK30.1, J3.12, J4.12, J5.12, J6.12, J7.12, J8.12, J9.2, J12.1, J14.1, R1.1, R2.1, R3.1, R4.1, R5.1, R6.1, R7.1, R12.1, R13.1, TP6.1, TP7.1, U1.7 (VCC), U2.16 (VCC), U3.14 (VCC), U4.16 (VCC), U5.16 (VCC), U6.16 (VCC), U7.16 (VCC), U10.28 (VCC), U11.28 (VCC), U12.28 (VCC), U13.28 (VCC), U14.28 (VCC), U15.28 (VCC), U16.28 (VCC), U18.28 (VCC), U20.12 (VCC), U21.12 (VCC), U22.14 (VCC), U23.15 (VDD), U28.20 (VCC), U29.20 (VCC), U30.20 (VCC), Y3.14 (Vcc), Y4.14 (Vcc); also elsewhere on the board
/$00: U2.15 (~Y0), U10.20 (~CS1)
/$20: U2.14 (~Y1), U11.20 (~CS1)
/$40: U2.13 (~Y2), U12.20 (~CS1)
/$60: U2.12 (~Y3), U13.20 (~CS1)
/$80: U2.11 (~Y4), U14.20 (~CS1)
/$A0: U2.10 (~Y5), U15.20 (~CS1)
/$C0: U2.9 (~Y6), U16.20 (~CS1)
/$D00n: U6.15 (~Y0), U20.9 (~CS2)
/$D00x: IO01.1, U5.15 (~Y0), U6.4 (~E0), U6.5 (~E1)
/$D01n: U6.14 (~Y1), U21.9 (~CS2)
/$D02n: U6.13 (~Y2), U22.15 (~CS0)
/$D03n: U6.12 (~Y3), U23.3 (~CS1)
/$D04n: U6.11 (~Y4), U28.23 (~CS2)
/$D05n: U6.10 (~Y5), U29.23 (~CS2)
/$D06n: U6.9 (~Y6), U30.23 (~CS2)
/$D07n: IO02.1, U6.7 (~Y7)
/$E0: U2.7 (~Y7), U18.20 (~CE)
/A0: J14.2, U1.8 (A0), U10.10 (A0), U11.10 (A0), U12.10 (A0), U13.10 (A0), U14.10 (A0), U15.10 (A0), U16.10 (A0), U18.10 (A0), U20.11 (RS), U21.11 (RS), U22.10 (RS0), U23.13 (RS0), U28.36 (RS0), U29.36 (RS0), U30.36 (RS0)
/A1: J14.3, U1.9 (A1), U10.9 (A1), U11.9 (A1), U12.9 (A1), U13.9 (A1), U14.9 (A1), U15.9 (A1), U16.9 (A1), U18.9 (A1), U20.8 (CS0), U21.8 (CS0), U22.11 (RS1), U23.14 (RS1), U28.35 (RS1), U29.35 (RS1), U30.35 (RS1)
/A2: J14.14, U1.10 (A2), U10.8 (A2), U11.8 (A2), U12.8 (A2), U13.8 (A2), U14.8 (A2), U15.8 (A2), U16.8 (A2), U18.8 (A2), U20.10 (CS1), U21.10 (CS1), U22.12 (RS2), U23.2 (CS0), U28.22 (CS0), U29.22 (CS0), U30.22 (CS0)
/A3: J14.15, U1.11 (A3), U10.7 (A3), U11.7 (A3), U12.7 (A3), U13.7 (A3), U14.7 (A3), U15.7 (A3), U16.7 (A3), U18.7 (A3), U22.16 (CS1), U28.24 (CS1), U29.24 (CS1), U30.24 (CS1)
/A4: U1.12 (A4), U6.1 (A0), U10.6 (A4), U11.6 (A4), U12.6 (A4), U13.6 (A4), U14.6 (A4), U15.6 (A4), U16.6 (A4), U18.6 (A4)
/A5: U1.13 (A5), U6.2 (A1), U10.5 (A5), U11.5 (A5), U12.5 (A5), U13.5 (A5), U14.5 (A5), U15.5 (A5), U16.5 (A5), U18.5 (A5)
/A6: U1.14 (A6), U6.3 (A2), U10.4 (A6), U11.4 (A6), U12.4 (A6), U13.4 (A6), U14.4 (A6), U15.4 (A6), U16.4 (A6), U18.4 (A6)
/A7: U1.15 (A7), U5.1 (A0), U10.3 (A7), U11.3 (A7), U12.3 (A7), U13.3 (A7), U14.3 (A7), U15.3 (A7), U16.3 (A7), U18.3 (A7)
/A8: U1.16 (A8), U5.2 (A1), U10.25 (A8), U11.25 (A8), U12.25 (A8), U13.25 (A8), U14.25 (A8), U15.25 (A8), U16.25 (A8), U18.25 (A8)
/A9: U1.17 (A9), U5.3 (A2), U10.24 (A9), U11.24 (A9), U12.24 (A9), U13.24 (A9), U14.24 (A9), U15.24 (A9), U16.24 (A9), U18.24 (A9)
/A10: U1.18 (A10), U4.1 (A0), U10.21 (A10), U11.21 (A10), U12.21 (A10), U13.21 (A10), U14.21 (A10), U15.21 (A10), U16.21 (A10), U18.21 (A10)
/A11: U1.19 (A11), U4.2 (A1), U10.23 (A11), U11.23 (A11), U12.23 (A11), U13.23 (A11), U14.23 (A11), U15.23 (A11), U16.23 (A11), U18.23 (A11)
/A12: U1.20 (A12), U4.3 (A2), U10.2 (A12), U11.2 (A12), U12.2 (A12), U13.2 (A12), U14.2 (A12), U15.2 (A12), U16.2 (A12), U18.2 (A12)
/A13: U1.21 (A13), U2.1 (A0), U4.4 (~E0)
/A14: U1.22 (A14), U2.2 (A1), U3.11
/A15: U1.23 (A15), U2.3 (A2), U4.6 (E2)
/CA11: J5.10, U29.40 (CA1)
/CA12: J5.11, U29.39 (CA2)
/CA21: J3.10, U28.40 (CA1)
/CA22: J3.11, U28.39 (CA2)
/CA31: J7.10, U30.40 (CA1)
/CA32: J7.11, U30.39 (CA2)
/CB11: J6.10, U29.18 (CB1)
/CB12: J6.11, U29.19 (CB2)
/CB21: J4.10, U28.18 (CB1)
/CB22: J4.11, U28.19 (CB2)
/CB31: J8.10, U30.18 (CB1)
/CB32: J8.11, U30.19 (CB2)
/D0: J14.5, U1.31 (D0), U10.11 (I/O0), U11.11 (I/O0), U12.11 (I/O0), U13.11 (I/O0), U14.11 (I/O0), U15.11 (I/O0), U16.11 (I/O0), U18.11 (D0), U20.22 (D0), U21.22 (D0), U22.25 (D0), U23.18 (D0), U28.33 (D0), U29.33 (D0), U30.33 (D0)
/D1: J14.6, U1.30 (D1), U10.12 (I/O1), U11.12 (I/O1), U12.12 (I/O1), U13.12 (I/O1), U14.12 (I/O1), U15.12 (I/O1), U16.12 (I/O1), U18.12 (D1), U20.21 (D1), U21.21 (D1), U22.24 (D1), U23.19 (D1), U28.32 (D1), U29.32 (D1), U30.32 (D1)
/D2: J14.7, U1.29 (D2), U10.13 (I/O2), U11.13 (I/O2), U12.13 (I/O2), U13.13 (I/O2), U14.13 (I/O2), U15.13 (I/O2), U16.13 (I/O2), U18.13 (D2), U20.20 (D2), U21.20 (D2), U22.23 (D2), U23.20 (D2), U28.31 (D2), U29.31 (D2), U30.31 (D2)
/D3: J14.8, U1.28 (D3), U10.15 (I/O3), U11.15 (I/O3), U12.15 (I/O3), U13.15 (I/O3), U14.15 (I/O3), U15.15 (I/O3), U16.15 (I/O3), U18.15 (D3), U20.19 (D3), U21.19 (D3), U22.22 (D3), U23.21 (D3), U28.30 (D3), U29.30 (D3), U30.30 (D3)
/D4: J14.9, U1.27 (D4), U10.16 (I/O4), U11.16 (I/O4), U12.16 (I/O4), U13.16 (I/O4), U14.16 (I/O4), U15.16 (I/O4), U16.16 (I/O4), U18.16 (D4), U20.18 (D4), U21.18 (D4), U22.21 (D4), U23.22 (D4), U28.29 (D4), U29.29 (D4), U30.29 (D4)
/D5: J14.10, U1.26 (D5), U10.17 (I/O5), U11.17 (I/O5), U12.17 (I/O5), U13.17 (I/O5), U14.17 (I/O5), U15.17 (I/O5), U16.17 (I/O5), U18.17 (D5), U20.17 (D5), U21.17 (D5), U22.20 (D5), U23.23 (D5), U28.28 (D5), U29.28 (D5), U30.28 (D5)
/D6: J14.11, U1.25 (D6), U10.18 (I/O6), U11.18 (I/O6), U12.18 (I/O6), U13.18 (I/O6), U14.18 (I/O6), U15.18 (I/O6), U16.18 (I/O6), U18.18 (D6), U20.16 (D6), U21.16 (D6), U22.19 (D6), U23.24 (D6), U28.27 (D6), U29.27 (D6), U30.27 (D6)
/D7: J14.12, U1.24 (D7), U10.19 (I/O7), U11.19 (I/O7), U12.19 (I/O7), U13.19 (I/O7), U14.19 (I/O7), U15.19 (I/O7), U16.19 (I/O7), U18.19 (D7), U20.15 (D7), U21.15 (D7), U22.18 (D7), U23.25 (D7), U28.26 (D7), U29.26 (D7), U30.26 (D7)
/E-clock: J14.13, U1.34 (E), U2.6 (E2), U20.14 (E), U21.14 (E), U22.17 (E), U23.27 (PHI2), U28.25 (ENABLE), U29.25 (ENABLE), U30.25 (ENABLE)
/PA10: J5.2, U29.2 (PA0)
/PA11: J5.3, U29.3 (PA1)
/PA12: J5.4, U29.4 (PA2)
/PA13: J5.5, U29.5 (PA3)
/PA14: J5.6, U29.6 (PA4)
/PA15: J5.7, U29.7 (PA5)
/PA16: J5.8, U29.8 (PA6)
/PA17: J5.9, U29.9 (PA7)
/PA20: J3.2, U28.2 (PA0)
/PA21: J3.3, U28.3 (PA1)
/PA22: J3.4, U28.4 (PA2)
/PA23: J3.5, U28.5 (PA3)
/PA24: J3.6, U28.6 (PA4)
/PA25: J3.7, U28.7 (PA5)
/PA26: J3.8, U28.8 (PA6)
/PA27: J3.9, U28.9 (PA7)
/PA30: J7.2, U30.2 (PA0)
/PA31: J7.3, U30.3 (PA1)
/PA32: J7.4, U30.4 (PA2)
/PA33: J7.5, U30.5 (PA3)
/PA34: J7.6, U30.6 (PA4)
/PA35: J7.7, U30.7 (PA5)
/PA36: J7.8, U30.8 (PA6)
/PA37: J7.9, U30.9 (PA7)
/PB10: J6.2, U29.10 (PB0)
/PB11: J6.3, U29.11 (PB1)
/PB12: J6.4, U29.12 (PB2)
/PB13: J6.5, U29.13 (PB3)
/PB14: J6.6, U29.14 (PB4)
/PB15: J6.7, U29.15 (PB5)
/PB16: J6.8, U29.16 (PB6)
/PB17: J6.9, U29.17 (PB7)
/PB20: J4.2, U28.10 (PB0)
/PB21: J4.3, U28.11 (PB1)
/PB22: J4.4, U28.12 (PB2)
/PB23: J4.5, U28.13 (PB3)
/PB24: J4.6, U28.14 (PB4)
/PB25: J4.7, U28.15 (PB5)
/PB26: J4.8, U28.16 (PB6)
/PB27: J4.9, U28.17 (PB7)
/PB30: J8.2, U30.10 (PB0)
/PB31: J8.3, U30.11 (PB1)
/PB32: J8.4, U30.12 (PB2)
/PB33: J8.5, U30.13 (PB3)
/PB34: J8.6, U30.14 (PB4)
/PB35: J8.7, U30.15 (PB5)
/PB36: J8.8, U30.16 (PB6)
/PB37: J8.9, U30.17 (PB7)
/PTM_o1: J1.1, U22.27 (O1)
/PTM_o2: J1.3, U22.3 (O2)
/PTM_o3: J1.5, U22.6 (O3)
/SPA_TxD: J20.2, U20.6 (Tx_Data)
/SPA_~CTS: J20.7, U20.24 (~CTS), ~{CTS}_1.1 (A)
/SPA_~DCD: J20.8, U20.23 (~DCD), ~{DCD}_1.1 (A)
/SPA_~RTS: J20.6, U20.5 (~RTS)
/SPB_RxD: J21.3, U21.2 (Rx_Data)
/SPB_TxD: J21.2, U21.6 (Tx_Data)
/SPB_~CTS: J21.7, U21.24 (~CTS), ~{CTS}_2.1 (A)
/SPB_~DCD: J21.8, U21.23 (~DCD), ~{DCD}_2.1 (A)
/SPB_~RTS: J21.6, U21.5 (~RTS)
/SPC_RxD: J23.3, U23.12 (RxD)
/SPC_TxD: J23.2, U23.10 (TxD)
/SPC_~CTS: J23.7, U23.9 (~CTS), ~{CTS}_3.1 (A)
/SPC_~DCD: J23.8, U23.16 (~DCD), ~{DCD}_3.1 (A)
/SPC_~DSR: J23.10, U23.17 (~DSR), ~{DSR}_3.1 (A)
/SPC_~DTR: J23.9, U23.11 (~DTR)
/SPC_~RTS: J23.6, U23.8 (~RTS)
/clk_RS1: J2.1, JP10.2 (B), U20.3 (Rx_CLK), U20.4 (Tx_CLK)
/clk_RS2: J2.2, JP11.2 (B), U21.3 (Rx_CLK), U21.4 (Tx_CLK)
/~A14: U3.10, U4.5 (~E1)
/~IO-sel: Pio1.2 (B), Pio2.2 (B), Pio3.2 (B), Pio4.2 (B), Pio5.2 (B), Pio6.2 (B), Pio7.2 (B), Pio8.2 (B), U5.4 (~E0), U5.5 (~E1), U16.26 (CS2)
/~Read: U3.12, U10.22 (~OE), U11.22 (~OE), U12.22 (~OE), U13.22 (~OE), U14.22 (~OE), U15.22 (~OE), U16.22 (~OE), U18.22 (~OE)
/~Write: J14.16, U1.32 (R/~W), U3.13, U10.27 (~WE), U11.27 (~WE), U12.27 (~WE), U13.27 (~WE), U14.27 (~WE), U15.27 (~WE), U16.27 (~WE), U20.13 (R/~W), U21.13 (R/~W), U22.13 (R/~W), U23.28 (R~W), U28.21 (R/~W), U29.21 (R/~W), U30.21 (R/~W)
FIRQ: R5.2, U1.4 (~FIRQ), U20.7 (~IRQ), U21.7 (~IRQ), U23.26 (~IRQ)
GND: AK1.2, AK2.2, AK3.2, AK5.2, AK10.2, AK11.2, AK12.2, AK13.2, AK14.2, AK15.2, AK16.2, AK17.2, AK20.2, AK21.2, AK22.2, AK28.2, AK29.2, AK30.2, C1.2, C2.1, C3.2, C4.1, C5.2, J1.2, J1.4, J1.6, J3.1, J4.1, J5.1, J6.1, J7.1, J8.1, J9.1, J13.1, J14.17, J20.1, J21.1, J23.1, PTM_C1.2 (B), PTM_C2.2 (B), PTM_C3.2 (B), PTM_G1.2 (B), PTM_G2.2 (B), PTM_G3.2 (B), SW1.1, TP1.1, TP2.1, TP3.1, TP4.1, TP5.1, U1.1 (VSS), U2.4 (~E0), U2.5 (~E1), U2.8 (GND), U3.1, U3.3, U3.5, U3.7 (GND), U3.9, U4.8 (GND), U5.8 (GND), U6.8 (GND), U7.8 (GND), U7.11 (CLR), U10.14 (GND), U11.14 (GND), U12.14 (GND), U13.14 (GND), U14.14 (GND), U15.14 (GND), U16.14 (GND), U18.1 (VPP), U18.14 (GND), U20.1 (VSS), U21.1 (VSS), U22.1 (VSS), U23.1 (VSS), U28.1 (VSS), U29.1 (VSS), U30.1 (VSS), Y3.7 (GND), Y4.7 (GND), ~{CTS}_1.2 (B), ~{CTS}_2.2 (B), ~{CTS}_3.2 (B), ~{DCD}_1.2 (B), ~{DCD}_2.2 (B), ~{DCD}_3.2 (B), ~{DSR}_3.2 (B); also elsewhere on the board
IRQ: R4.2, U1.3 (~IRQ), U22.9 (~IRQ), U28.37 (~IRQB), U28.38 (~IRQA), U29.37 (~IRQB), U29.38 (~IRQA), U30.37 (~IRQB), U30.38 (~IRQA)
NMI: R3.2, U1.2 (~NMI)
unnamed: IO01.2, U5.14 (~Y1)
unnamed: IO01.3, U5.13 (~Y2)
unnamed: IO01.4, U5.12 (~Y3)
unnamed: IO01.5, U5.11 (~Y4)
unnamed: IO01.6, U5.10 (~Y5)
unnamed: IO01.7, U5.9 (~Y6)
unnamed: IO01.8, U5.7 (~Y7)
unnamed: J10.1, J11.1, U7.9 (QA)
unnamed: J10.3, J11.3, U7.7 (QB)
unnamed: J10.5, J11.5, U7.6 (QC)
unnamed: J10.7, J11.7, U7.5 (QD)
unnamed: J10.9, J11.9, U7.3 (QE)
unnamed: J10.2, J10.4, J10.6, J10.8, J10.10, J10.12, J10.14, J10.16, J10.18, J10.20, J10.22, J10.24, JP10.1 (A)
unnamed: J10.11, J11.11, U7.2 (QF)
unnamed: J10.13, J11.13, U7.4 (QG)
unnamed: J10.15, J11.15, U7.13 (QH)
unnamed: J10.17, J11.17, U7.12 (QI)
unnamed: J10.19, J11.19, U7.14 (QJ)
unnamed: J10.21, J11.21, U7.15 (QK)
unnamed: J10.23, J11.23, U7.1 (QL)
unnamed: J11.2, J11.4, J11.6, J11.8, J11.10, J11.12, J11.14, J11.16, J11.18, J11.20, J11.22, J11.24, JP11.1 (A)
unnamed: J20.3, U20.2 (Rx_Data)
unnamed: PTM_C1.1 (A), U22.28 (~C1)
unnamed: PTM_C2.1 (A), U22.4 (~C2)
unnamed: PTM_C3.1 (A), U22.7 (~C3)
unnamed: PTM_G1.1 (A), U22.26 (~G1)
unnamed: PTM_G2.1 (A), U22.2 (~G2)
unnamed: PTM_G3.1 (A), U22.5 (~G3)
unnamed: Pio1.1 (A), U4.15 (~Y0)
unnamed: Pio2.1 (A), U4.14 (~Y1)
unnamed: Pio3.1 (A), U4.13 (~Y2)
unnamed: Pio4.1 (A), U4.12 (~Y3)
unnamed: Pio5.1 (A), U4.11 (~Y4)
unnamed: Pio6.1 (A), U4.10 (~Y5)
unnamed: Pio7.1 (A), U4.9 (~Y6)
unnamed: Pio8.1 (A), U4.7 (~Y7)
unnamed: BA1.1, U1.6 (BA)
unnamed: BS1.1, U1.5 (BS)
unnamed: C1.1, U1.38 (EXTAL), Y1.1
unnamed: R2.2, U1.33 (~DMA/BREQ), U1.36 (MRDY), U1.40 (~HALT)
unnamed: Q1.1, U1.35 (Q)
unnamed: C2.2, U1.39 (XTAL), Y1.2
unnamed: R6.2, U5.6 (E2)
unnamed: R7.2, U6.6 (E2)
unnamed: U7.10 (CLK), Y4.8 (OUT)
unnamed: R12.2, U10.26 (CS2), U11.26 (CS2), U12.26 (CS2), U13.26 (CS2), U14.26 (CS2), U15.26 (CS2), U18.26 (NC)
unnamed: R13.2, U18.27 (~PGM)
unnamed: C5.1, U23.6 (XTLI), Y2.1, Y3.8 (OUT)
unnamed: C4.2, U23.7 (XTLO), Y2.2
~RESET: C3.1, J14.4, R1.2, SW1.2, U1.37 (~RESET), U22.8 (~RESET), U23.4 (~RES), U28.34 (~RESET), U29.34 (~RESET), U30.34 (~RESET)

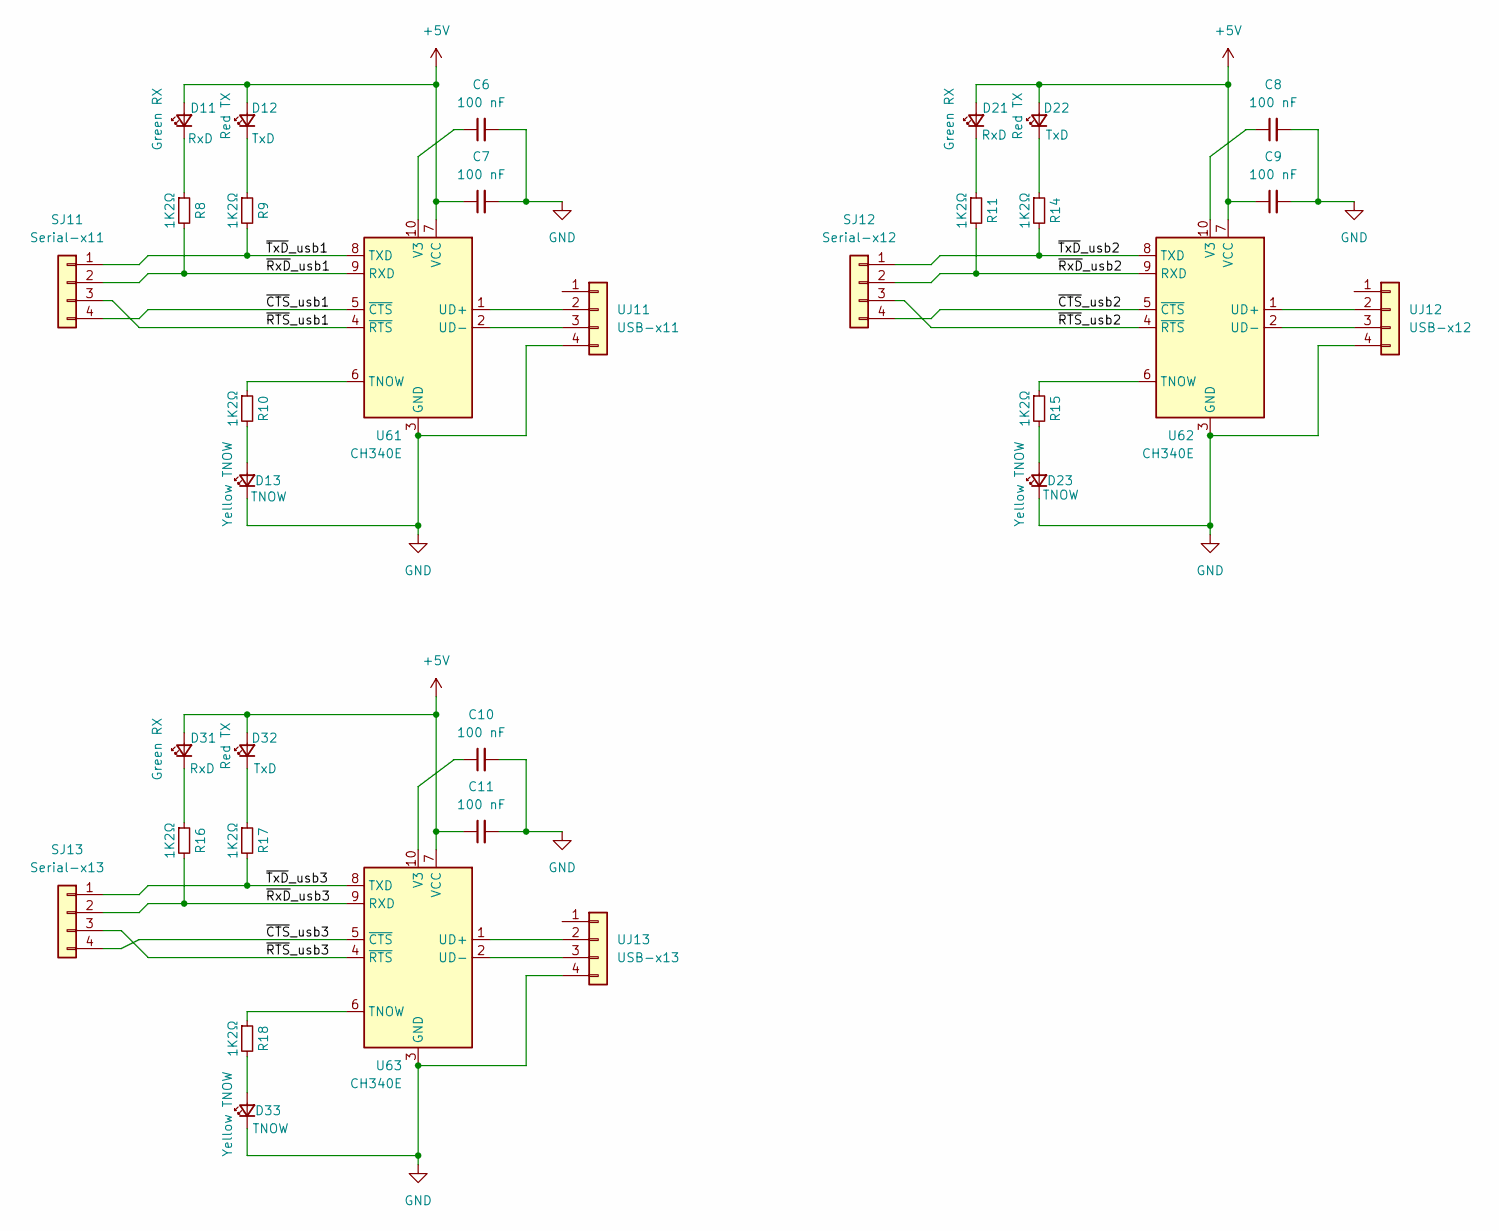
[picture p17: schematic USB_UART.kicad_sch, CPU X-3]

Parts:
C6, C7, C8, C9, C10, C11: 100 nF; C_Axial_L3.8mm_D2.6mm_P7.50mm_Horizontal
D11, D21, D31: Green RX; LED_D3.0mm
D12, D22, D32: Red TX; LED_D3.0mm
D13, D23, D33: Yellow TNOW; LED_D3.0mm
R8, R9, R10, R11, R14, R15, R16, R17, R18: 1K2Ω; R_Axial_DIN0207_L6.3mm_D2.5mm_P10.16mm_Horizontal
SJ11: Serial-x11; PinHeader_1x04_P2.54mm_Vertical
SJ12: Serial-x12; PinHeader_1x04_P2.54mm_Vertical
SJ13: Serial-x13; PinHeader_1x04_P2.54mm_Vertical
U61, U62, U63: CH340E; MSOP-10_3x3mm_P0.5mm-CH340E
UJ11: USB-x11; PinHeader_1x04_P2.54mm_Vertical
UJ12: USB-x12; PinHeader_1x04_P2.54mm_Vertical
UJ13: USB-x13; PinHeader_1x04_P2.54mm_Vertical

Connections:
+5V: C7.1, C9.1, C11.1, D11.2 (A), D12.2 (A), D21.2 (A), D22.2 (A), D31.2 (A), D32.2 (A), U61.7 (VCC), U62.7 (VCC), U63.7 (VCC); also elsewhere on the board
/USB-UART/~CTS_usb1: SJ11.4, U61.5 (~CTS)
/USB-UART/~CTS_usb2: SJ12.4, U62.5 (~CTS)
/USB-UART/~CTS_usb3: SJ13.4, U63.5 (~CTS)
/USB-UART/~RTS_usb1: SJ11.3, U61.4 (~RTS)
/USB-UART/~RTS_usb2: SJ12.3, U62.4 (~RTS)
/USB-UART/~RTS_usb3: SJ13.3, U63.4 (~RTS)
/USB-UART/~RxD_usb1: R8.2, SJ11.2, U61.9 (RXD)
/USB-UART/~RxD_usb2: R11.2, SJ12.2, U62.9 (RXD)
/USB-UART/~RxD_usb3: R16.2, SJ13.2, U63.9 (RXD)
/USB-UART/~TxD_usb1: R9.2, SJ11.1, U61.8 (TXD)
/USB-UART/~TxD_usb2: R14.2, SJ12.1, U62.8 (TXD)
/USB-UART/~TxD_usb3: R17.2, SJ13.1, U63.8 (TXD)
GND: C6.2, C7.2, C8.2, C9.2, C10.2, C11.2, D13.1 (K), D23.1 (K), D33.1 (K), U61.3 (GND), U62.3 (GND), U63.3 (GND), UJ11.4, UJ12.4, UJ13.4; also elsewhere on the board
unnamed: D11.1 (K), R8.1
unnamed: D12.1 (K), R9.1
unnamed: D13.2 (A), R10.2
unnamed: D21.1 (K), R11.1
unnamed: D22.1 (K), R14.1
unnamed: D23.2 (A), R15.2
unnamed: D31.1 (K), R16.1
unnamed: D32.1 (K), R17.1
unnamed: D33.2 (A), R18.2
unnamed: R10.1, U61.6 (TNOW)
unnamed: U61.1 (UD+), UJ11.2
unnamed: U61.2 (UD-), UJ11.3
unnamed: C6.1, U61.10 (V3)
unnamed: R15.1, U62.6 (TNOW)
unnamed: U62.1 (UD+), UJ12.2
unnamed: U62.2 (UD-), UJ12.3
unnamed: C8.1, U62.10 (V3)
unnamed: R18.1, U63.6 (TNOW)
unnamed: U63.1 (UD+), UJ13.2
unnamed: U63.2 (UD-), UJ13.3
unnamed: C10.1, U63.10 (V3)

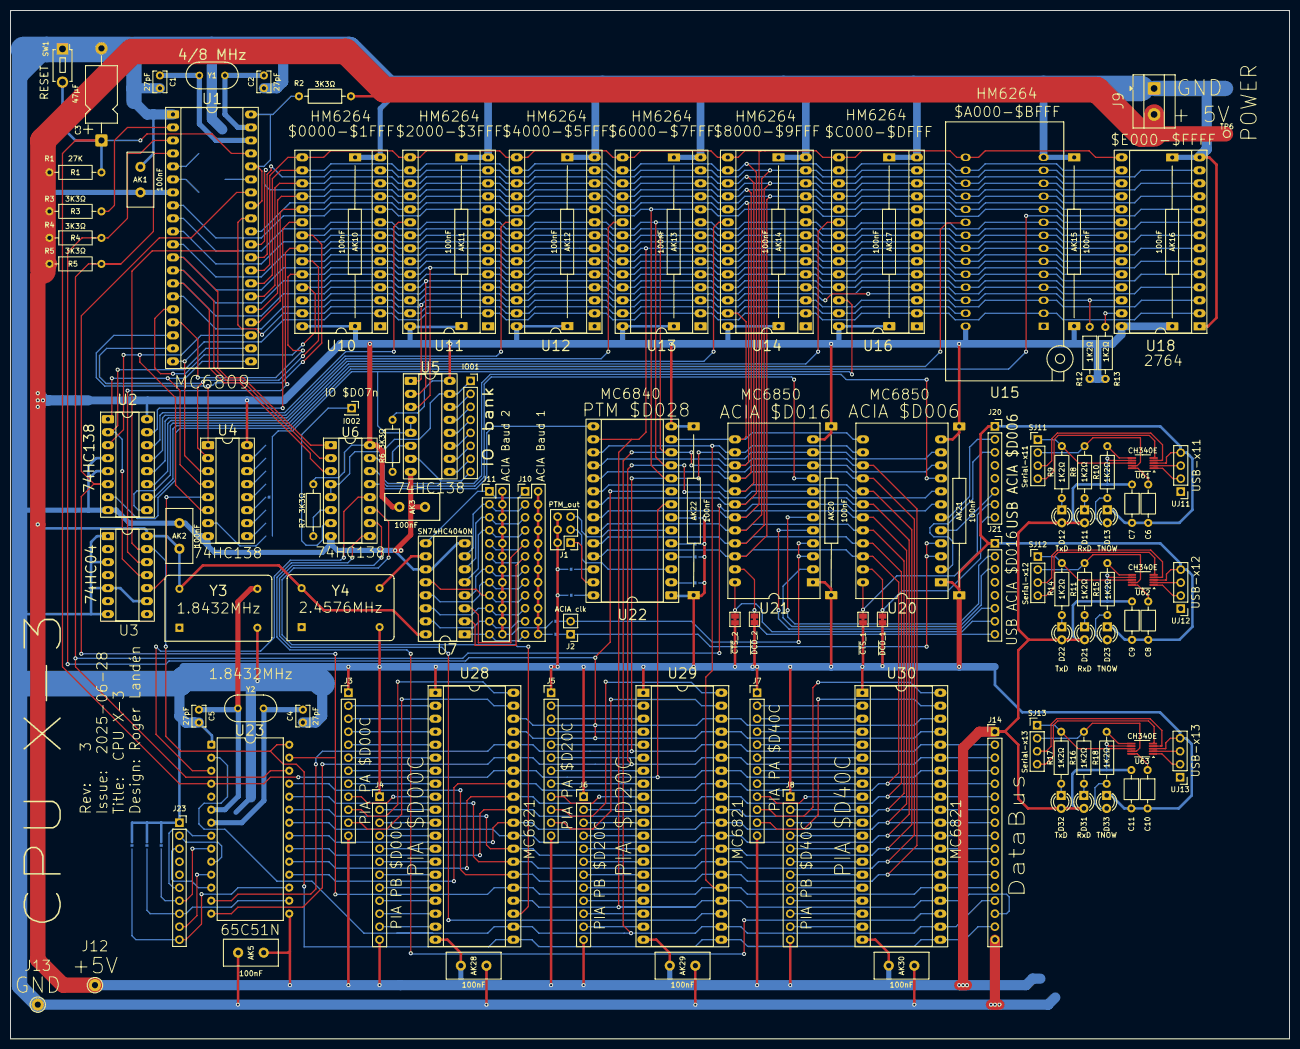
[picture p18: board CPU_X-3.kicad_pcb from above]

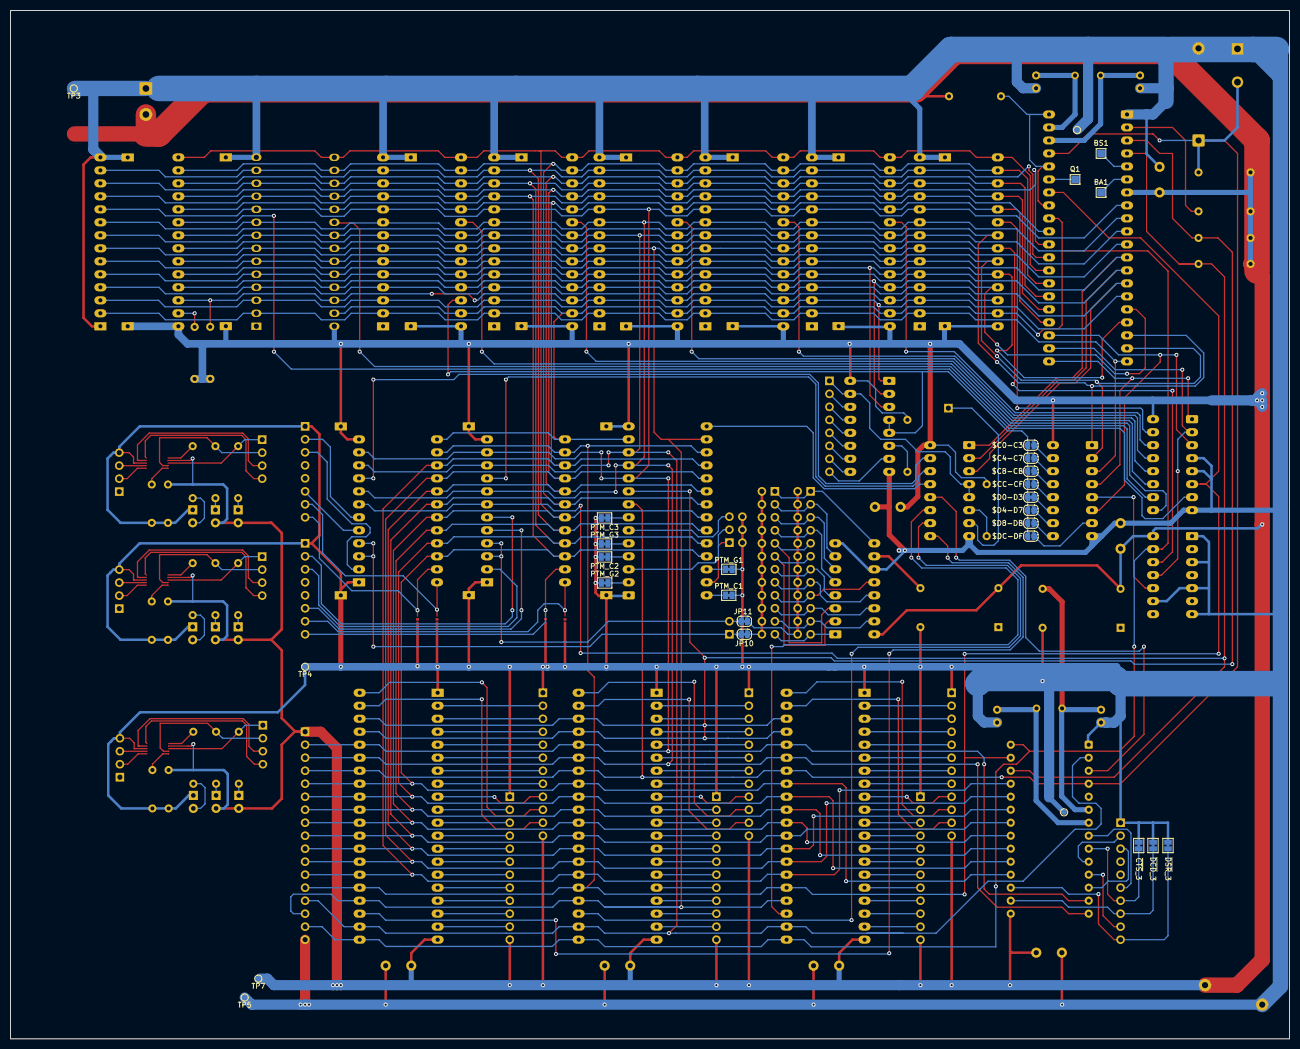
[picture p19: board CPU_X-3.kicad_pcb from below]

Board: 2 copper layers, 250.0 x 201.0 mm, 137 parts (25 on the bottom side), 215 nets.

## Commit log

2025-09-09 Added the KiCAD of CPU X-3 rev 3
    [CPU_X-3-B_Cu.gbl, CPU_X-3-B_Mask.gbs, CPU_X-3-B_Paste.gbp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]
2025-09-09 Add PCB card picture
